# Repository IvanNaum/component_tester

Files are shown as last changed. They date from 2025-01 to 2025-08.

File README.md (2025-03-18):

# Component tester

## Naumov I

## Project Structure 

- [docs](docs/) - pdf documets/drafts
- [simulation](simulation/) - modeling of processes
- [software](software/) - common modules, tests, sdk and mcu software
- [hardware](hardware/) - schematics, PCB files
- [construction](construction/) - 3D models, CAD files

## Codestyles

1. Install pre-commit
```shell
pip install pre-commit
pre-commit install
```

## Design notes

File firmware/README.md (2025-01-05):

# Firmware 

## Project Structure 

- [common](common/) - contains common modules, host and tests
- [stm32f1_example/](stm32f1_example/) - led blink example on bluepill stm32f1
- [template/](template/) - template to copy to your project
- [host/](host/) - host platform project, allows to test common code on host

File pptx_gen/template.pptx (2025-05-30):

МИНИСТЕРСТВО НАУКИ И ВЫСШЕГО ОБРАЗОВАНИЯ РОССИЙСКОЙ ФЕДЕРАЦИИ
МОСКОВСКИЙ ГОСУДАРСТВЕННЫЙ ТЕХНИЧЕСКИЙ УНИВЕРСИТЕТ ИМ. Н.Э. БАУМАНА
КАФЕДРА ПРОЕКТИРОВАНИЕ И ТЕХНОЛОГИЯ ПРОИЗВОДСТВА ЭЛЕКТРОННОЙ АППАРАТУРЫ






Отчет о выполнении курсовой работы по предмету: «Электроника и микроэлектроника» на тему: «Тестер компонентов на базе микроконтроллера STM32F103C8T6»






Выполнил: студент группы ИУ4-62Б
Наумов И.К.
Проверил: Руководитель курсовой работы
Чистяков М.Г.



Москва, 2024 г.

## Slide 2

- {{E1.pdf}}

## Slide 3

- {{E2.pdf}}

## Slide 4

- {{E3.pdf}}

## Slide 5

- {{PE3.pdf}}

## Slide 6

- {{PP.pdf}}

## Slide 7

- {{SB.pdf}}

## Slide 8

- {{speka.pdf}}

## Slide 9

- {{modeling.pdf}}

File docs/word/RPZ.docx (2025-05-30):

Министерство науки и высшего образования Российской Федерации

Федеральное государственное бюджетное образовательное учреждение

высшего образования

«Московский государственный технический университет имени Н.Э. Баумана

(национальный исследовательский университет)»

(МГТУ им. Н.Э. Баумана)

ФАКУЛЬТЕТ «Информатика и системы управления» («ИУ»)

КАФЕДРА «Проектирование и технология производства электронной аппаратуры» («ИУ-4»)

РАСЧЕТНО-ПОЯСНИТЕЛЬНАЯ ЗАПИСКА

к курсовой работе на тему:

«Разработка устройства «Тестер компонентов на базе микроконтроллера STM32F103C8T6»

Студент | __________________________ | Наумов И. К.
| (Подпись, дата)
Руководитель курсовой работы | __________________________ | Чистяков М. Г.
| (Подпись, дата)

Москва, 2024
Аннотация

Работа описывает процесс разработки устройства «Тестера компонентов на базе микроконтроллера STM32F103C8T6». Данный тестер позволяет определять пассивные и активные компоненты

Работа содержит комплекс документов по разработке устройства: схема электрическая структурная; схема электрическая принципиальная; чертеж печатной платы; сборочный чертеж электронной ячейки; спецификация; перечень элементов. В заключении представлены выводы о проделанной работе и соответствии разработанного устройства техническому заданию.

Ключевые слова: тестер компонентов, контроль качества (AOI), STM32F103C8T6.

## Abstract

The work describes the development process of the "Component Tester Based on the STM32F103C8T6 Microcontroller." This tester allows identifying passive and active electronic components.

The work includes a comprehensive set of documentation for the device: a block diagram, an electrical schematic diagram, a printed circuit board (PCB) layout, an assembly drawing of the electronic unit, a specification, and a bill of materials. The conclusion summarizes the outcomes of the work and confirms that the developed device meets the technical requirements.

Keywords: component tester, quality control (AOI), STM32F103C8T6.

# СОДЕРЖАНИЕ

# Список условных обозначений, сокращений и терминов

ГОСТ – Государственный стандарт;

ДПП – Двухсторонняя печатная плата;

ЕСКД – Единая система конструкторской документации;

ПП – Печатная плата;

РПЗ – Расчётно-пояснительная записка;

РТЗ – Расширенное техническое задание;

ТЗ – Техническое задание;

ЭРЭ – Электрорадиоэлементы;

КМО – Компонент, монтируемый в отверстия

УГО – Условное графическое обозначение

# Введение

Работа посвящена разработке и исследованию устройства «Тестер компонентов на базе микроконтроллера STM32F103C8T6».

Целью работы является разработка устройства «Тестер компонентов на базе микроконтроллера STM32F103C8T6», разработка комплекта конструкторской документации, а также экспериментальное исследование устройства для выявления его соответствию техническим требованиям и пригодности к эксплуатации.

Для достижения поставленной задачи был решен следующий комплекс работ:

1. Разработка схемы электрической структурной (Э1);

2. Разработка схемы электрической функциональной (Э2);

3. Разработка схемы электрической принципиальной (Э3);

4. Моделирование работы устройства;

5. Разработка конструкции устройства;

6. Сборка опытного образца устройства;

7. Экспериментальные исследования устройства.

Исходными данными для работы являются:

- задание на выполнение курсовой работы;
- календарный план выполнения курсовой работы.

Результатами работы являются:

1. Схема электрическая структурная (Э1);
2. Схема электрическая функциональная (Э2);
3. Схема электрическая принципиальная (Э3);
4. Полнофункциональная модель в САПР “PSPICE 16.3”;
5. Чертеж печатной платы (ПП);
6. Сборочный чертеж (СБ);
7. Разработанный опытный образец;
8. Плакат демонстрационный.

# 1 Схемотехническое проектирование изделия «Тестер компонентов на базе микроконтроллера STM32F103C8T6»

Схемотехнический этап курсового проекта включает:

1. Разработка схемы электрической структурной (Э1) устройства;
2. Разработка схемы электрической функциональная (Э2) устройства;
3. Разработка схемы электрической принципиальной (Э3) устройства;
4. Подбор элементной базы устройства;
5. Разработка перечня элементов ПЭ3 устройства;

## 1.1 Разработка электрической структурной схемы (Э1)

Разработка схемы электрической структурной (Э1) предполагает первоначальную оценку работы и выделение основных структурных частей. Электрическая структурная схема устройства была разработана согласно ГОСТ 2.701-2008[7]. В качестве среды разработки была выбрана “Altium Designer 23.10.1”. Электрическая структурная схема изделия представлена на рисунке 1.1.

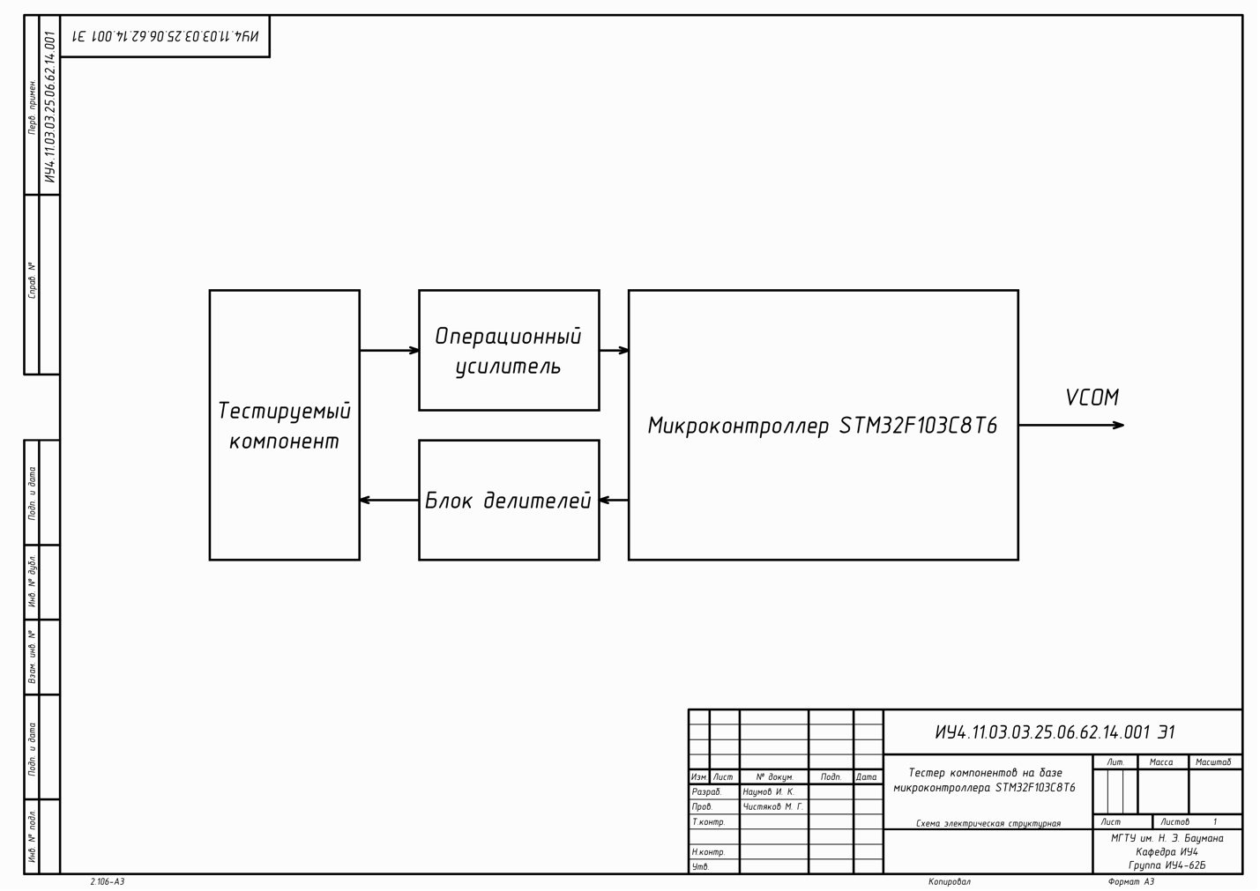
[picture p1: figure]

Рис. 1.1 – Электрическая структурная схема (Э1) устройства

Все устройство можно условно разделить на 3 функциональных блоков:

- Операционный усилитель – блок для снижение выходного сопротивления перед АЦП микроконтроллера.
- Блок делителей – набор резисторов, управляемые микроконтроллером для реализации деления напряжения в цепи тестирования компонента.
- Микроконтроллер – основной управляющий элемент устройства, обеспечивает корректность его работы.

## 1.2 Разработка электрической функциональной схемы (Э2)

На основе схемы электрической структурной схемы, была разработана схема электрическая функциональная. Схема разработана по ГОСТ 2.702-2011[8], и представлена на рисунке 1.2.

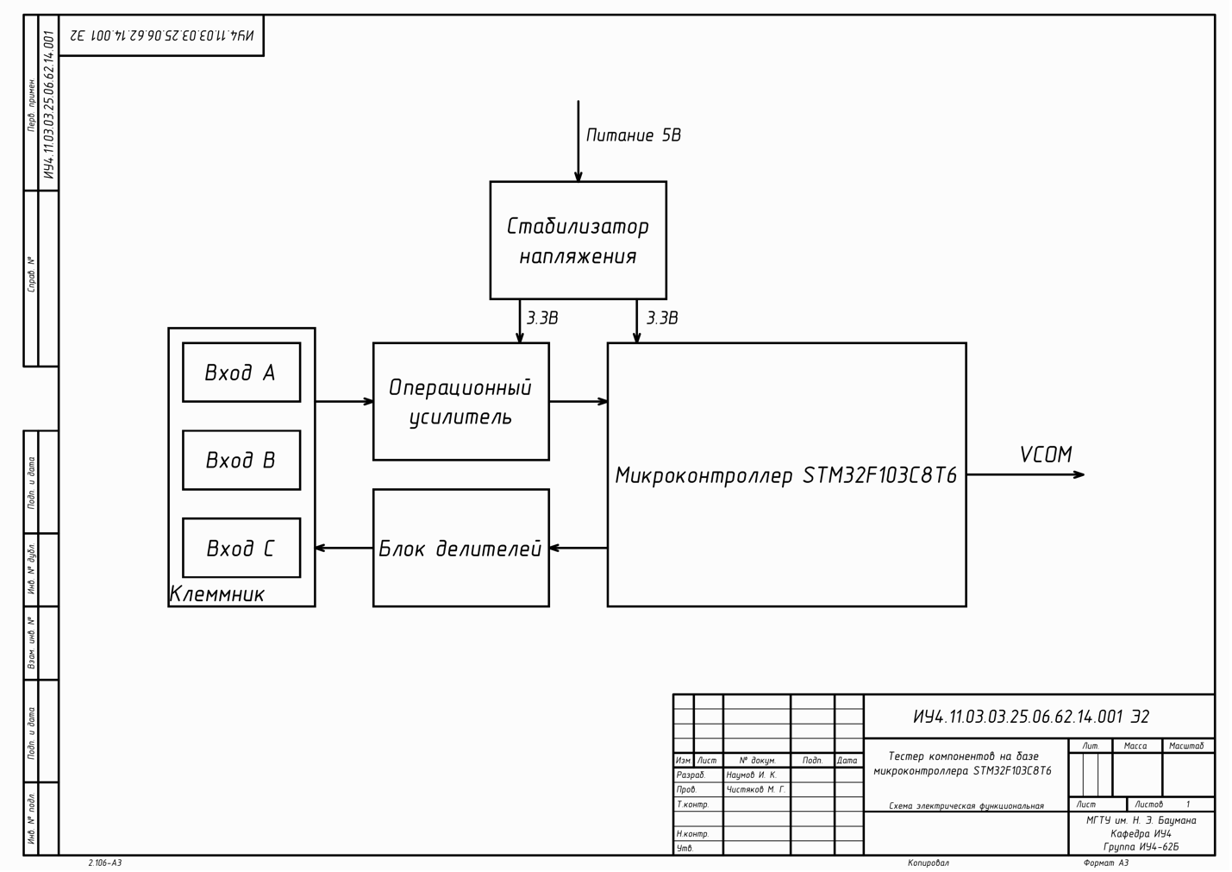
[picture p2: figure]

Рис. 1.2 – Электрическая функциональная схема (Э2) устройства

## 1.3 Разработка электрической принципиальной схемы (Э3)

На основе схемы электрической структурной схемы, была разработана схема электрическая принципиальная. Схема разработана по ГОСТ 2.702-2011[8], и представлена на рисунке 1.3.

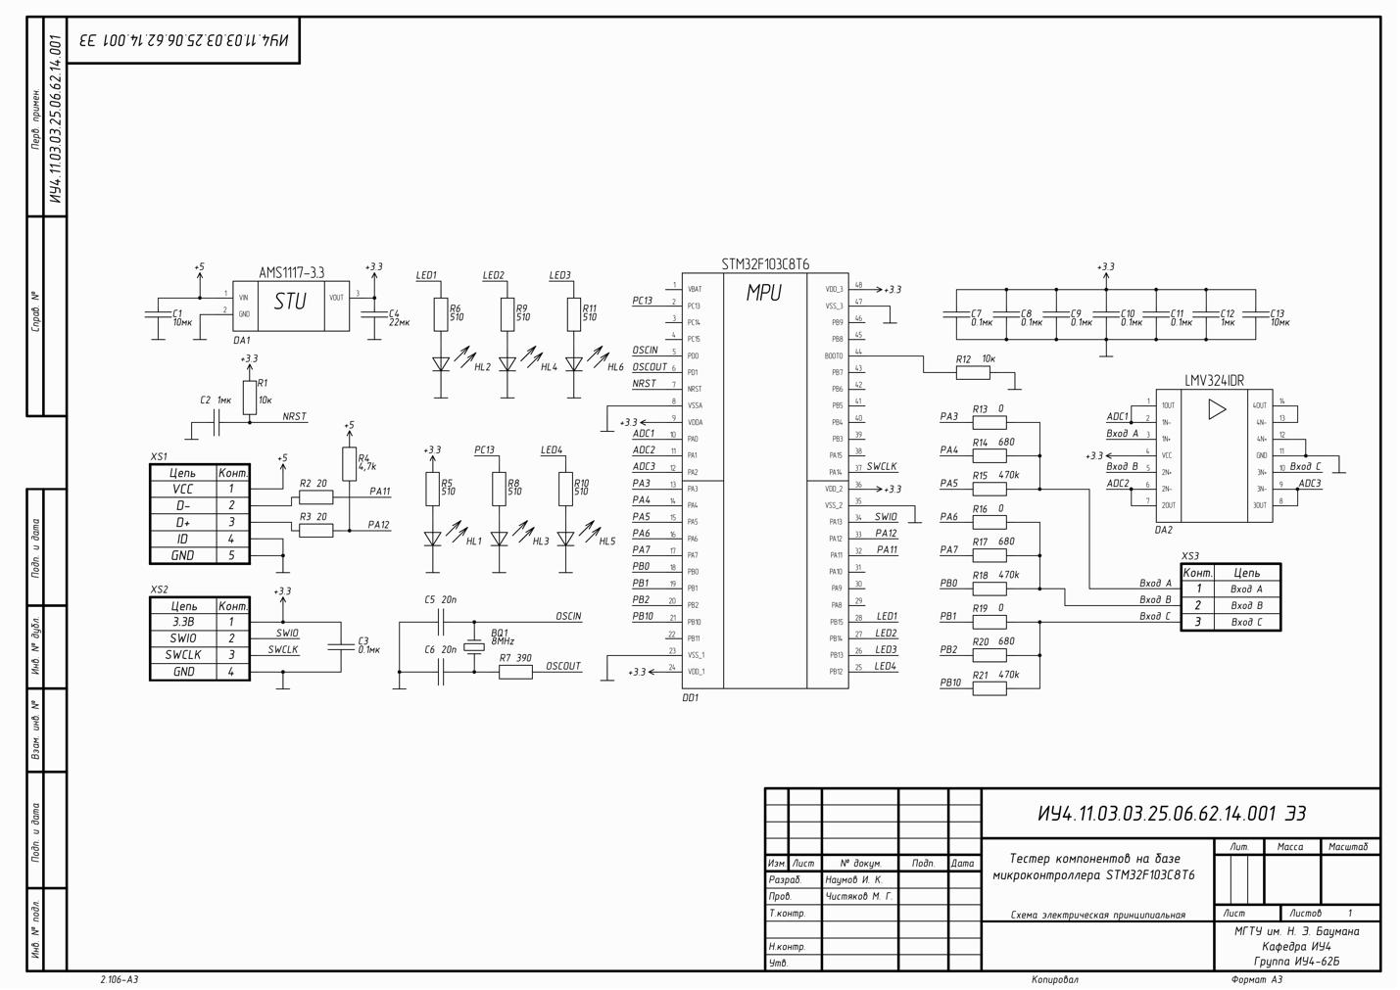
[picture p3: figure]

Рис. 1.3 – Электрическая принципиальная схема (Э3) устройства

Для индикации питания используется зелёный светодиод HL1, для пользовательской – красный HL3, для индикации тестируемого компонента – синие HL2, HL4, HL5, HL6. Формфактор 1206.

Разъём для программирования и отладки Serial Wire Debug (SWD) XS2 – PBS4, XS1 – USB type B mini, разъём для крепления тестируемого компонента XS3 – ZIF14.

Резисторы используются в формфакторе 1206, конденсаторы 0603.

Кварцевый резонатор BQ1 SMD 5×3.2 мм 8000 МГц.

Стабилизатор напряжения DA1 – AMS1117-3.3 3.3В 1А. Формфактор SOT-223.

Операционный усилитель DA2 – LMV324IDR, Низковольтный операционный усилитель, 1МГц, Rail-to-Rail. Формфактор SOIC-14.

Микроконтроллер DD1 – SMT32F103C8T6, Cortex-M3, 72МГц, 64КБ Flash. Формфактор LQFP-48.

## 1.4 Разработка перечня элементов (ПЭ3)

После выбора элементной базы был составлен перечень элементов схемы (ПЭ3) согласно ГОСТ 2.701-2008[7]. Перечень элементов (ПЭ3) представлен в документе ИУ4.11.03.03.25.06.62.15.001 ПЭ3 в приложении 1 и на рисунке 1.4.

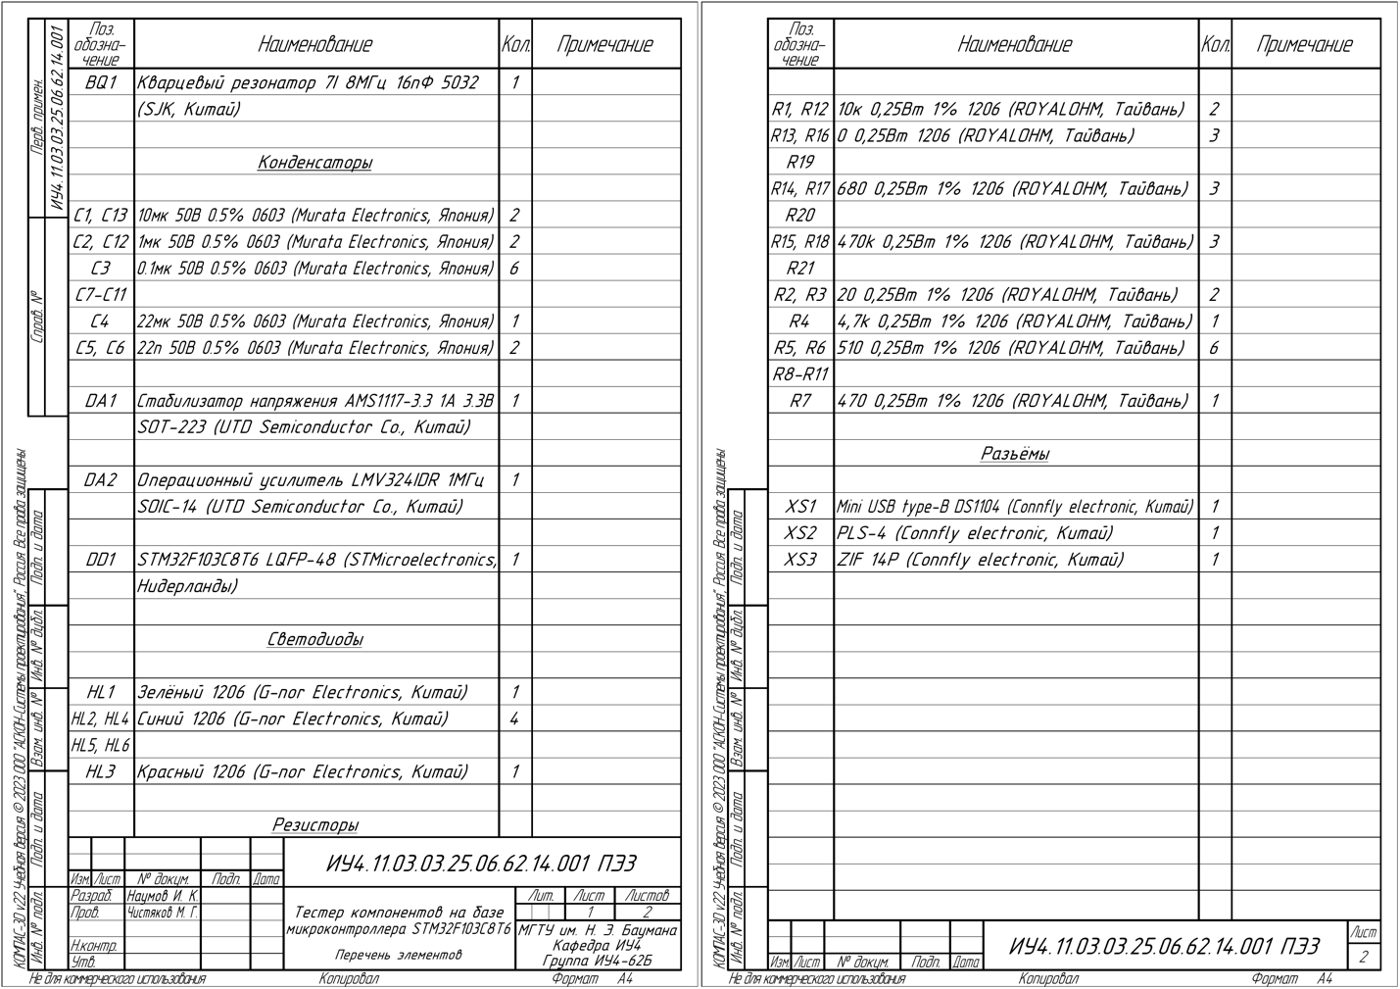
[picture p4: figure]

Рис. 1.4 – Перечень элементов (ПЭ3) устройства

## Вывод

В главе проведено схемотехническое проектирование изделия устройства «Тестер компонентов на базе микроконтроллера STM32F103C8T6». Была разработана схема электрическая структурная (Э1), в которой были выделены основные структурные узлы устройства. Данная схема представлена на чертеже ИУ4.11.03.03.25.06.62.15.001 Э1, а также на рисунке 1.1.

Далее была разработана схема электрическая функциональная (Э2), в которой функциональные соединения устройства. Данная схема представлена на чертеже ИУ4.11.03.03.25.06.62.15.001 Э2, а также на рисунке 1.2.

После была разработана схема электрическая принципиальная (Э3), в которой подробно описаны соединения всех ИЭТ устройства и благодаря условным графическим обозначениям однозначно определяется функционал каждого ИЭТ, а также обоснован выбор каждого ИЭТ. Данная схема представлена на чертеже ИУ4.11.03.03.25.06.62.15.001 Э3, а также на рисунке 1.3.

А также составлен перечень элементов. Документ ИУ4.11.03.03.25.06.62.15.001 ПЭ3 представлен в приложении 1 и на рисунке 1.4.

# 2 Описание алгоритма тестирования и моделирование устройства «Тестер компонентов на базе микроконтроллера STM32F103C8T6»

### Тестирование биполярных транзисторов

Исследование элемента необходимо начинать с обесточенным управляющим выводом (вывод С) исследуемого элемента. Во время испытания является базовым или отправным. Один испытательный вывод выбран положительной стороной элемента и подключен непосредственно к VCC. Другой испытательный вывод выбран отрицательной стороной элемента. Отрицательная сторона подсоединена через резистор 680 Ω к GND. Сначала, вывод C на 5 ms подключается через резистор 680 Ω Ом к GND и измеряется напряжение на отрицательной стороне. Далее вывод C переключается на Ввод (высокое полное входное сопротивление) и снова измеряется напряжение отрицательного испытательного вывода. Затем предполагаемая база соединяется через резистор 680 Ω на 5 ms к VCC и снова измеряется напряжение на отрицательной стороне. Если измеренное напряжение ниже первого результата измерения, то эта схема будет предполагаться, как правильная. Затем напряжение снова измеряется с обесточенным выводом C.

У биполярных транзисторов, имеющих повышенный обратный ток коллектора, он значительно повышается в режиме с обесточенной базой.

Если у элемента нет тока между положительным и отрицательным испытательными выводами без сигнала на выводе C, то переходим к тестам определения, описанным ниже. Если ток был обнаружен, то следующий тест описан в разделе о диодах.

Сначала измеряем коэффициент усиления предполагаемого P-N-P транзистора в схеме с общим коллектором (эмиттерный повторитель). Если напряжение базы (UB), измеренное с резистором 680 Ω, выше 9 mV, то коэффициент усиления вычисляется по формуле hFE = UE−UB. Напряжение UE это разность между напряжением на UB эмиттере и VCC. Если напряжение UB ниже 10 mV, измерение делают с резистором 470 kΩ в базе. В этом случае коэффициент усиления вычисляется по формуле hFE = UE·470000 / UB·680.

Затем делают тесты для предполагаемого P-N-P транзистора в схеме с общим эмиттером. Положительная сторона элемента теперь подключена прямо с VCC, отрицательная сторона через резистор 680 Ω подключена к GND. Если на отрицательной стороне элемента есть напряжение выше 1.6 V , когда базовый резистор 680 Ω подключен к GND, значит этот элемент P-N-P транзистор. Для того, чтобы измерить коэффициент усиления, в цепь базы вместо резистора 680 Ω включается резистор 470 kΩ. Коэффициент усиления вычисляется по формуле hFE =(UC −UC0)·470000 / UB·680. Напряжение UC0 является напряжением на коллекторном резисторе без базового тока. Как предполагается, правильным является более высокий коэффициент усиления, определенный первым или вторым способом.

Измерение N-P-N транзистора начинается таким же образом, как и P-N-P транзистора, с измерения коэффициента усиления в схеме с общим коллектором. Первое измерение сделано с резистором в цепи базы 680 Ω подключенным к VCC. Если напряжение на резисторе в цепи базы слишком низко, вместо 680 Ω берётся резистор 470 kΩ. Тогда измерение продолжается в схеме с общим эмиттером. Если напряжение коллектора ниже 1,6 V и резистор в цепи базы 680 Ω соединён с VCC, то это может быть N-P-N транзистор. Базовое напряжение N-P-N транзистора будет близко к напряжению эмиттера, таким образом, этот тип может быть идентифицирован определенно. Коэффициент усиления в схеме с общим эмиттером вычисляется по формуле hFE = (V CC−UC−UC0)·470000 / (V CC−UB)·(680+22).

### Тестирование диодов

Если предварительными тестами будет обнаружен ток, то элемент будет опознан как диод. Падение напряжения с резистором 680 Ω должно быть между 0,15 V и 3 V (в зависимости от расположения резистора).

### Тестирование резисторов

Измерение неизвестного резистора Rx осуществляется с использованием прецизионных резисторов 680 Ω. Схема этого измерения для испытательных выводов 1 и 2 представляет собой последовательное соединение прецизионного и тестируемого резистора. Величина резистора Rx может быть вычислена по известной величине резистора и измеренному напряжению, если отношение резистора Rx к 680 Ω не слишком велико. Теоретическое отклонение напряжения показано на рисунке 2.1 (слева), где величина резистора показана в логарифмическом масштабе.

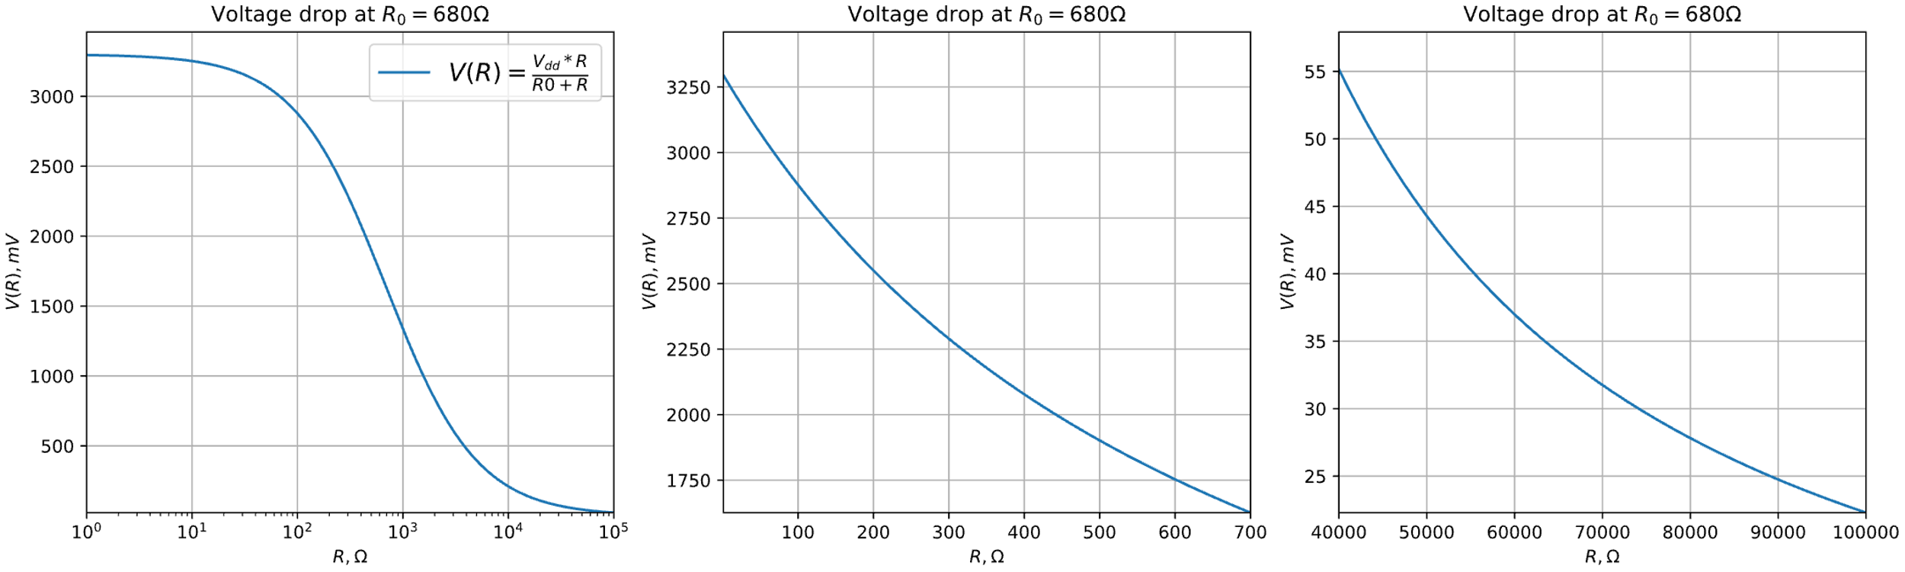
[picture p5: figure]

Рис. 2.1 – Падение напряжения при измерениях с резистором 680 Ω

График измерения на рисунке 2.1 (по центру) показан с измененным масштабом изображения для малых значений резисторов, на рисунке 2.1 (cправа) показан с измененным масштабом изображения для больших значений резисторов.

Для более высоких значений измеряемого резистора измерения проводятся с прецизионными резисторами 470 kΩ. Если все тесты свидетельствуют о том, что это не другой тип элемента, то полученная величина прямого и обратного измерений берется в качестве величины сопротивления резистора.

Теоретическое отклонение напряжения показано на рисунке 2.2 где величина резистора показана в логарифмическом масштабе. Теоретическое отклонение в этой диаграмме заканчивается на 100 MΩ, но фактическое значение для Тестера ограничено 60 MΩ, иначе устройство определяет, что резистор не подключен.

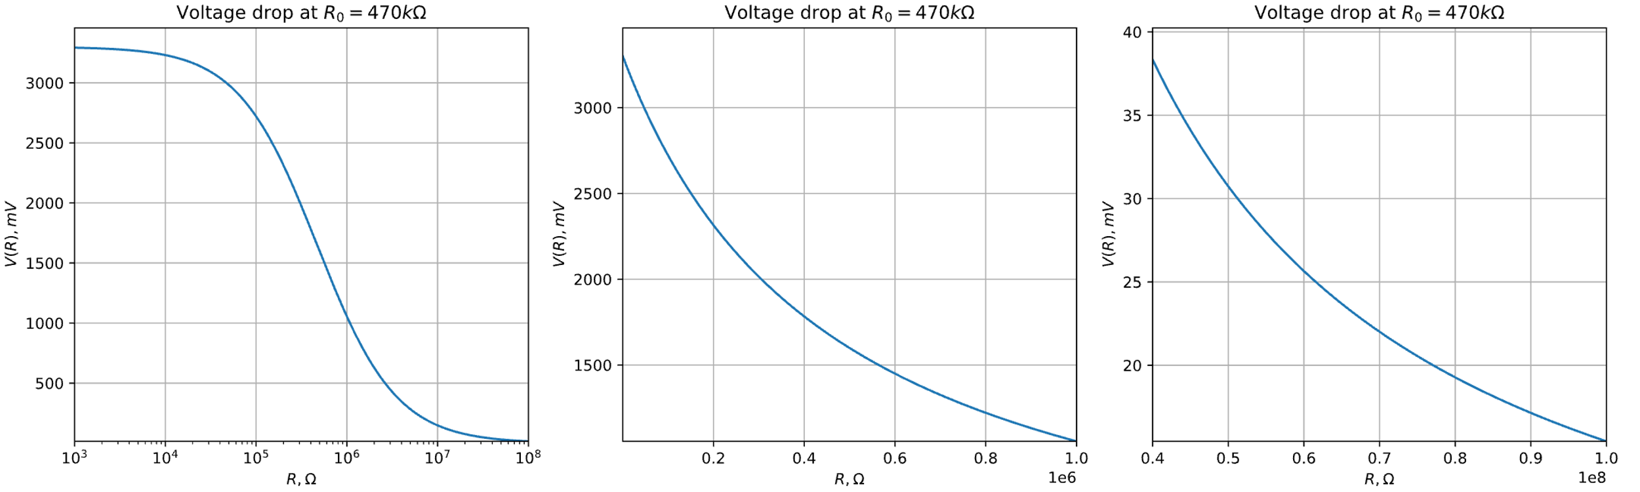
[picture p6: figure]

Рис. 2.2 – Падение напряжения при измерениях с резистором 470 kΩ

### Тестирование конденсаторов

Измерение величины ёмкости конденсаторов сделано, как отдельная задача измерения времени зарядки после всех других измерений. Положительный вывод конденсатора всегда подключен к испытательному выводу с более высоким номером (A). Если конденсатор измеряется параллельно с диодом, полярность может быть в другом порядке.

Необходимо разряжать конденсатор прежде, чем подсоединить его к устройству. Тестер дополнительно разряжает конденсатор перед любым измерением. Если напряжение ниже 1300 mV, конденсатор будет закорочен выходами порта, соединенными со входами порта АЦП.

Одна сторона конденсатора подключена к GND. Другая сторона конденсатора подключена через резистор 680 Ω к VCC на 10 ms. Впоследствии этот испытательный вывод будет переключён на ввод (высокий импеданс). После этого, 10 ms импульса тока, замеряется напряжение на конденсаторе без тока. Если напряжение не достигло минимального значения 300 mV, импульс зарядки будет повторен до 499 раз. Если после 127 импульсов не достигнуто минимальное напряжение 75 mV (приблизительно 0.2 s), дальнейшая зарядка будет остановлена, потому что 300 mV не смогут быть достигнуты остающимися импульсами зарядки. Пример тестирования конденсатора с величиной 10 mF показан на рисунке 2.3. Величина ёмкости вычисляется по количеству импульсов зарядки и величине достигнутого напряжения заряда из таблицы. Таблица содержит коэффициенты, чтобы получить значение в nF от времени зарядки и достигнутого напряжения с шагом 25 mV.

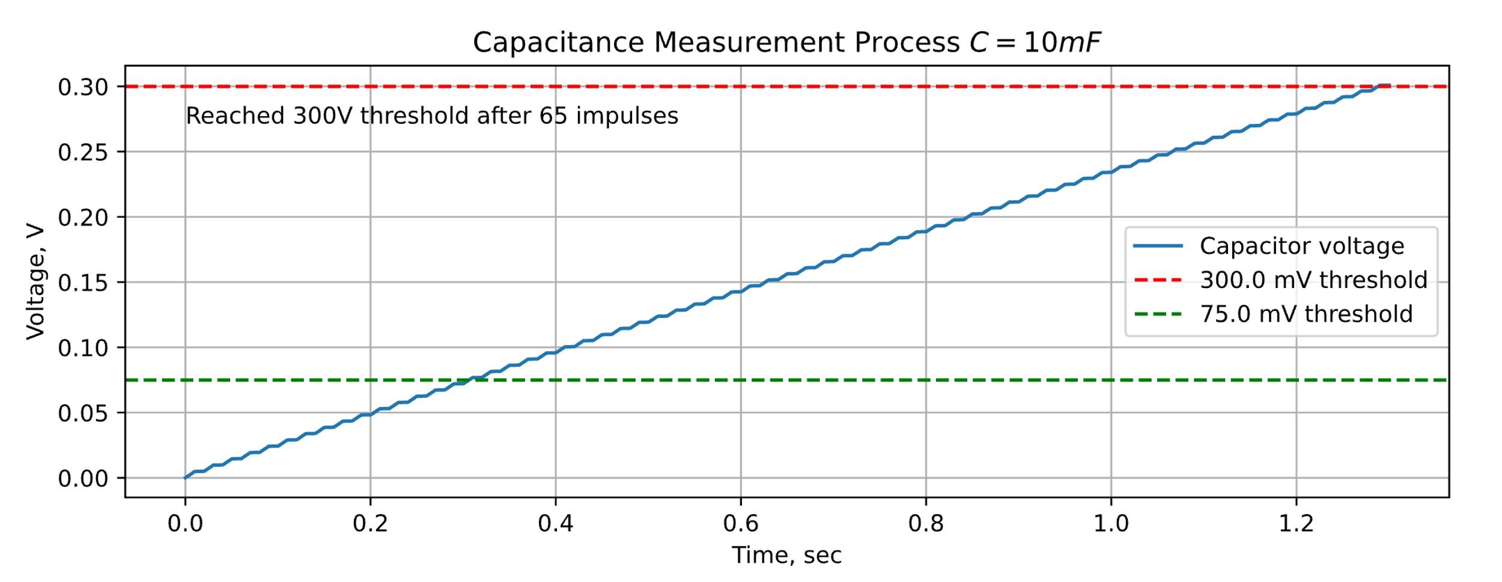
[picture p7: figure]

Рис. 2.3 –Напряжение на обкладках тестируемого конденсатора

После измерения ёмкости конденсатора будет проверен саморазряд ожиданием пропорционально периоду, который потребовала зарядка, и снова будет осуществлено считывание напряжения заряда. После чего полная ёмкость будет скорректирована. Возможный диапазон тестируемых конденсаторов с помощью данного метода показан на рисунке 2.4.

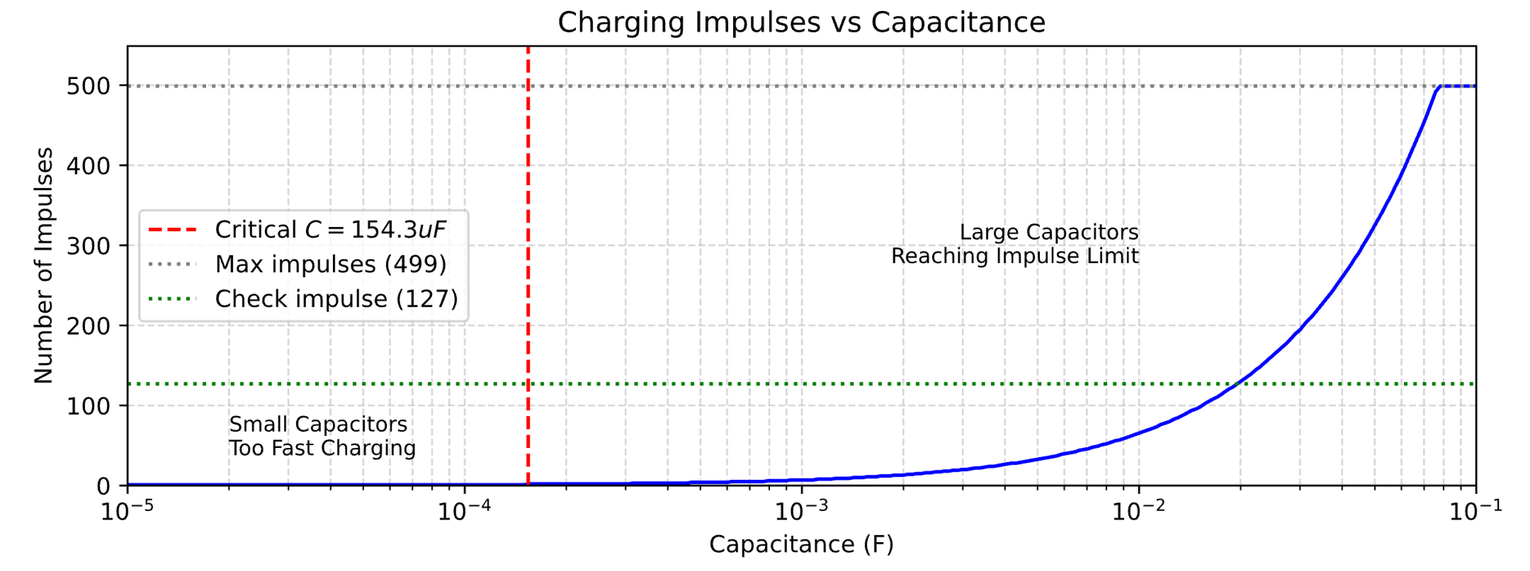
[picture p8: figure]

Рис. 2.4 – Диапазон тестируемых конденсаторов при заданном количестве импульсов

# 3 Конструкторско-технологическое проектирование устройства «Тестер компонентов на базе микроконтроллера STM32F103C8T6»

Конструкторско-технологический этап выполнения курсового проекта включает:

1. разработку топологии печатной платы (ПП);

2. разработку чертежа ПП;

3. разработку сборочного чертежа (СБ);

4. разработку спецификации (СП);

5. изготовление ПП и монтаж ЭРЭ.

## 3.1 Разработка топологии печатной платы (ПП)

В качестве среды разработки была выбрана программа для трассировки печатных плат «Altium Designer 23.10.1», результат работы представлен на рисунках 3.1 и 3.2:

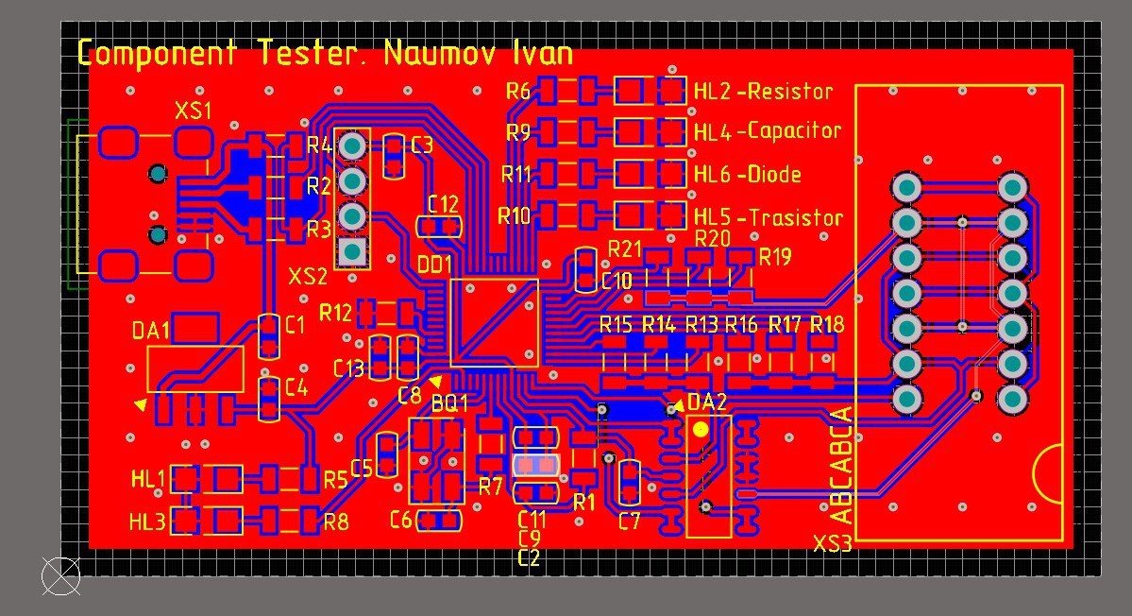
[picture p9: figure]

Рис. 3.1 – Трассировка ПП в программе “Altium Designer 23.10.1”

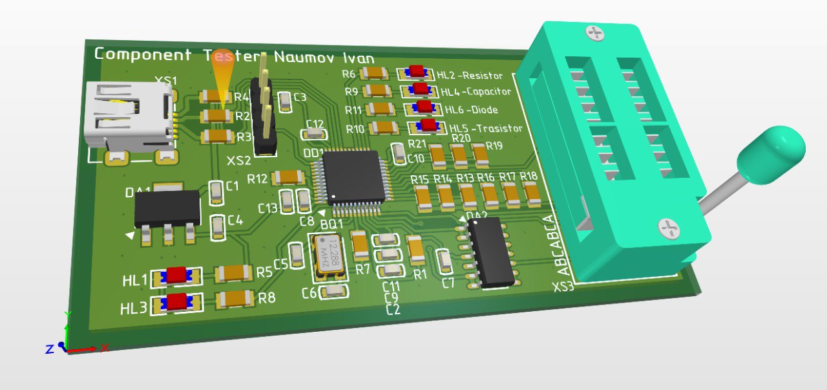
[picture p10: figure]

Рис. 3.2 – 3D-модель ячейки в программе “Altium Designer 23.10.1”

## 3.2 Разработка чертежа ПП

После трассировки был разработан чертеж ПП, который представлен на рисунке 3.3.

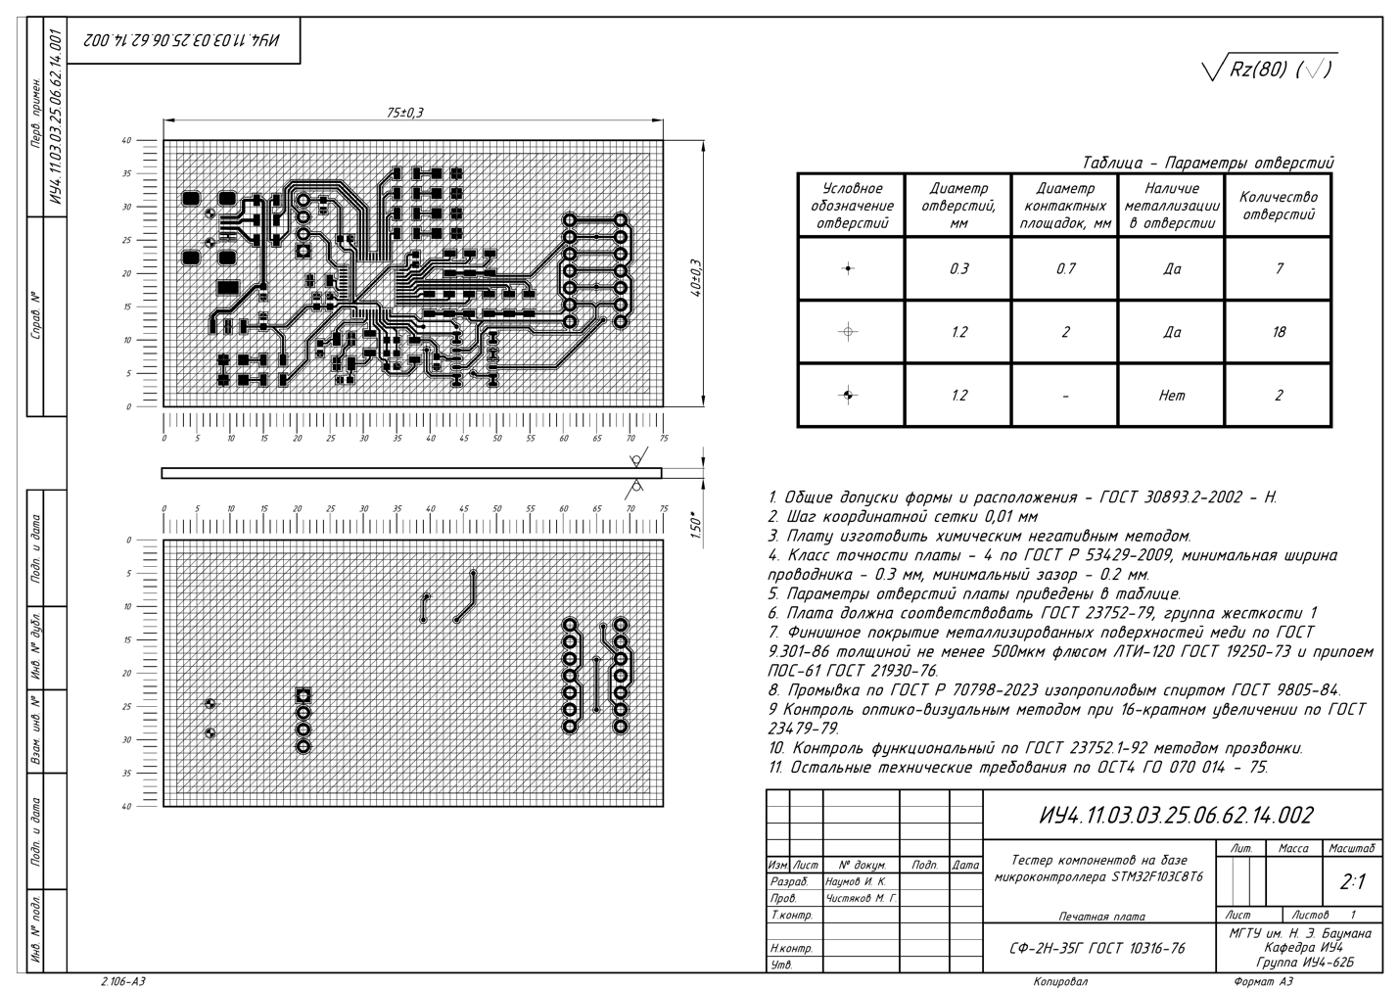
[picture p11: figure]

Рис. 3.3 – Чертеж печатной платы (ПП)

Плата представляет собой ДПП с габаритными размерами 75х40 мм. Проводящий рисунок изображен на рисунке 3.3 и на чертеже ИУ4.11.03.03.25.06.62.15.002.

Шаг координатной сетки 0.01 мм.

Плата соответствует требованиям ГОСТ 23752-79[9] (группа жёсткости 1).

Плата соответствует требованиям ГОСТ Р 53429-2009[10] (2 класс точности).

Минимальная ширина печатного проводника – 0.3 мм.

Минимальное расстояние между элементами проводящего рисунка – 0,2 мм.

Минимальный номинальный диаметр отверстия – 0,3 мм.

Материал платы – стеклотекстолит СФ-2Н-35Г ГОСТ 10316-76[11].

В печатной плате имеются отверстия различных типов, характеристика которых приведена в таблице 3.1, а также в таблице на чертеже ИУ4.11.03.03.25.06.62.15.002.

Таблица 3.1 – Таблица отверстий ПП

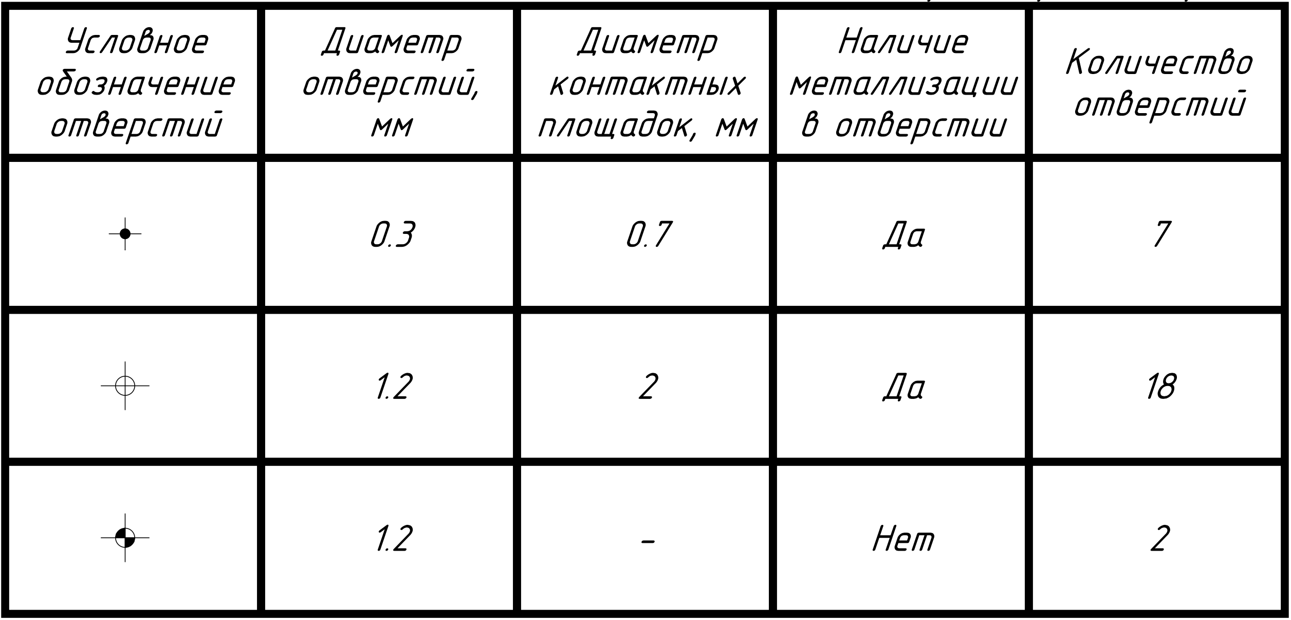
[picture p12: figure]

Общее количество отверстий – 27 отверстий.

Исходя из вышеперечисленных требований печатная плата опытного образца изготавливалась субтрактивным, негативным методом.

## 3.3 Разработка сборочного чертежа

Далее был разработан сборочный чертёж, представленный рисунке 3.4 и на чертеже ИУ4.11.03.03.25.06.62.15.001 СБ.

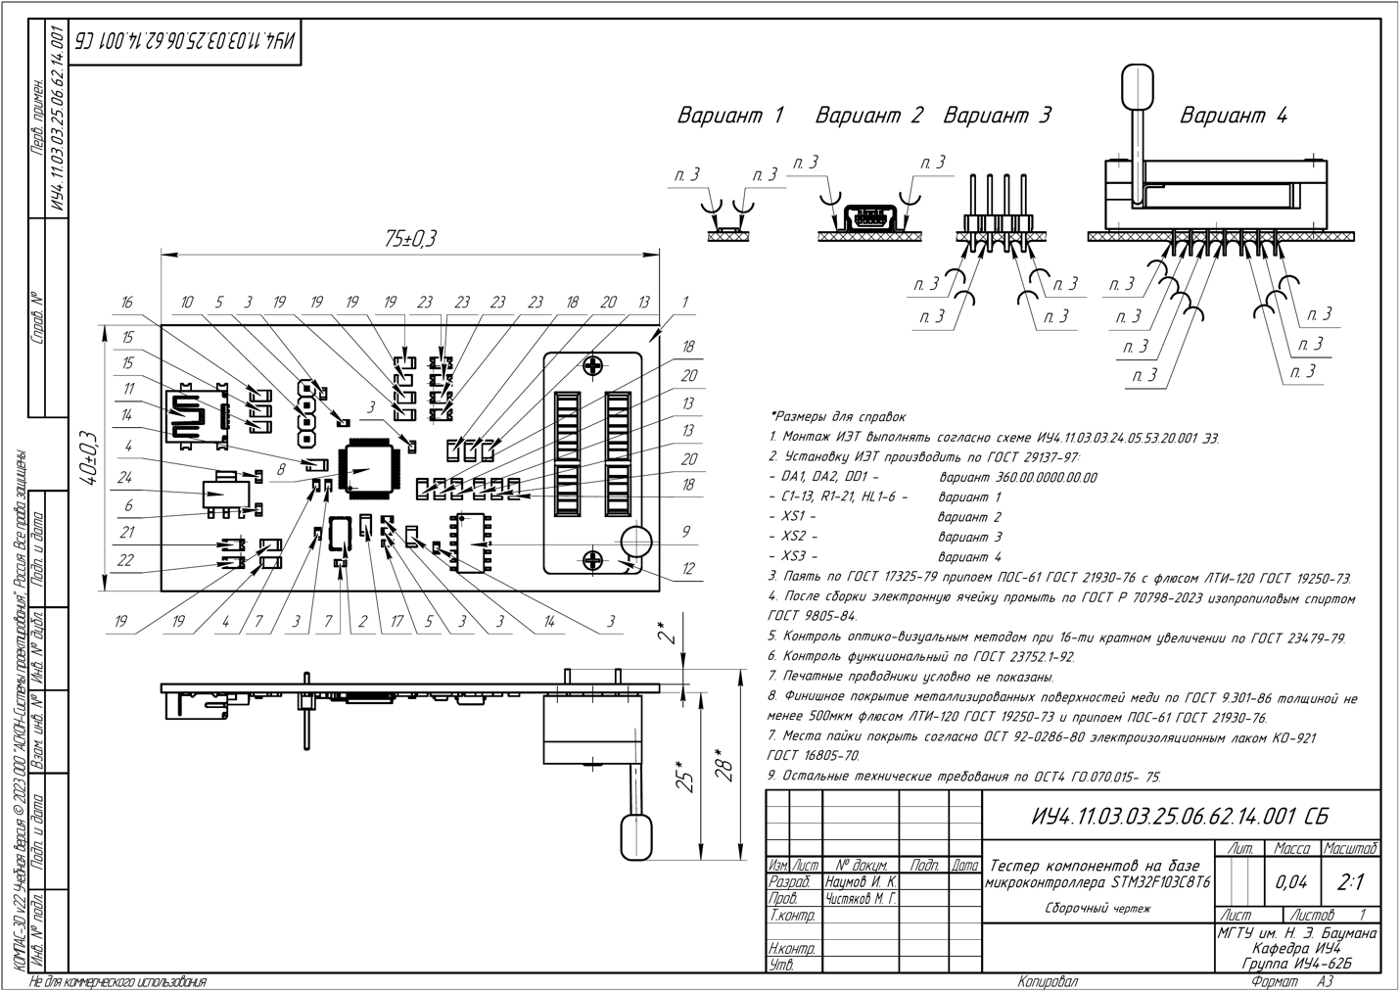
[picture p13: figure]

Рис. 3.4 – Сборочный чертеж электронной ячейки

Компоненты группируются по способу установки на плату. Установки формовка ИЭТ осуществляется согласно ГОСТ 29137-91[14]. Вариант установки приведены на чертеже ИУ4.11.03.03.25.06.62.15.001 СБ. Обозначения позиций согласно спецификации ИУ4.11.03.03.25.06.62.15.001.

Монтаж ИЭТ производится с одной стороны. Пайка выводов производится припоем ПОС-61 ГОСТ 21930-76[12] согласно ГОСТ 23592- 96[15]. Допускается применение импортного припоя. Габаритные размеры всего изделия составляют 75x40x28 мм. После сборки изделие промывают изопропиловым спиртом ГОСТ 9805-84. Контроль паяных соединений производится визуально-оптическим методом по ГОСТ 23479-79. Исходя из вышеперечисленных требований, при производстве опытного образца рекомендуется производить монтаж КМП припоем и капиллярной пайкой паяльником.

## 3.4 Разработка спецификации изделия

Спецификация – основной документ курсовой работы. В спецификацию вносят составные части, входящие в специфицируемое изделие, а также конструкторские документы, относящиеся к этому изделию и к его неспецифицируемым составным частям.

Спецификация на устройство была разработана согласно ГОСТ 2.106[18] в графическом редакторе «Компас-3D v23», представлена на рисунке 3.5 и состоит из следующих разделов в соответствующей последовательности:

− документация;

− детали;

− прочие изделия.

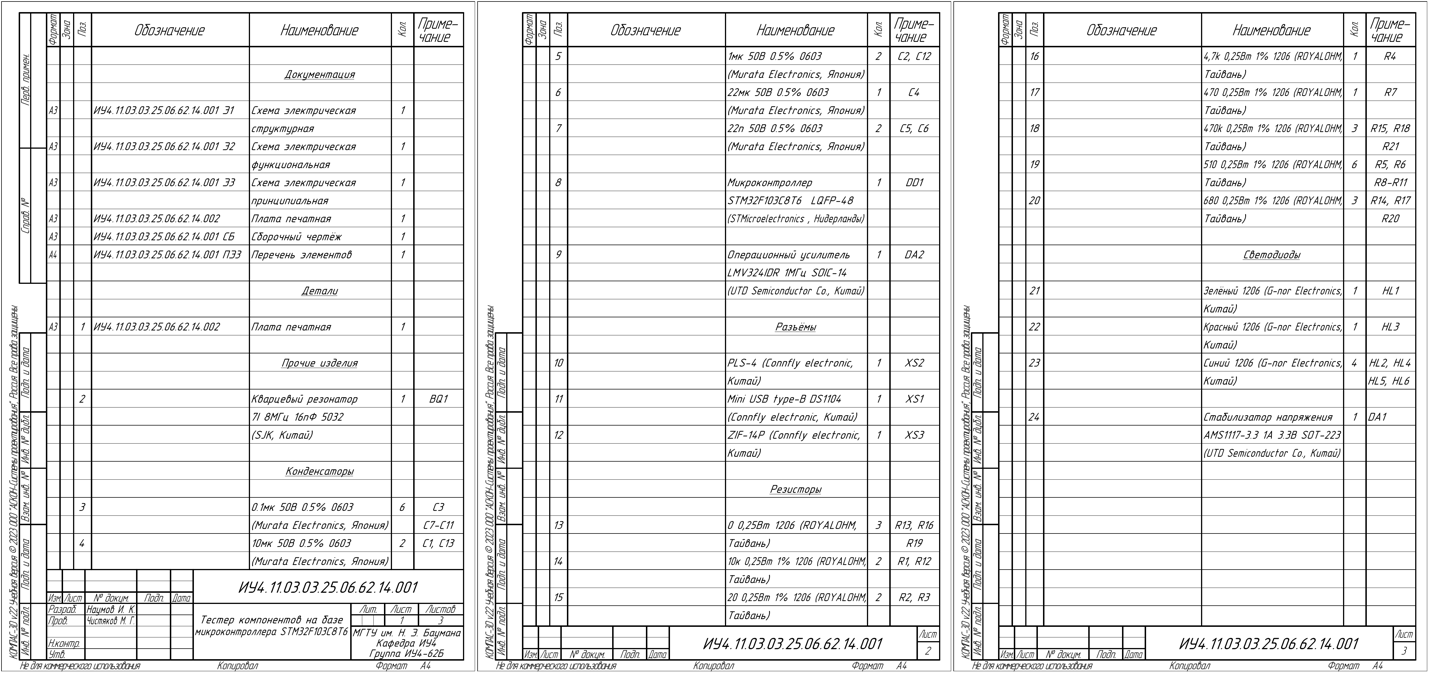
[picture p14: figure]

Рис. 3.5 – Спецификация на устройство

В раздел «Документация» внесены все документы, составляющие основной комплект конструкторских документов специфицируемого изделия, кроме самой спецификации и перечня элементов.

В раздел «Детали» была внесена деталь, непосредственно входящая в специфицируемое изделие – плата печатная.

Раздел «Прочие изделия» схож по наполнению с перечнем элементов (ПЭ3), за исключением того, запись изделий в пределах каждой группы происходит в алфавитном порядке наименований изделий, а обозначение УГО элементов записываются в графу «Примечание».

## 3.5 Изготовление ПП и монтаж ЭРЭ

Печатная плата изготавливалась на заводе компании «NextPCB» в соответствии с указанными выше требованиями.

Монтаж компонентов производился согласно схеме ИУ4.11.03.03.25.06.62.15.001 Э3. Фотография изготовленного устройства представлена на рисунке 2.6

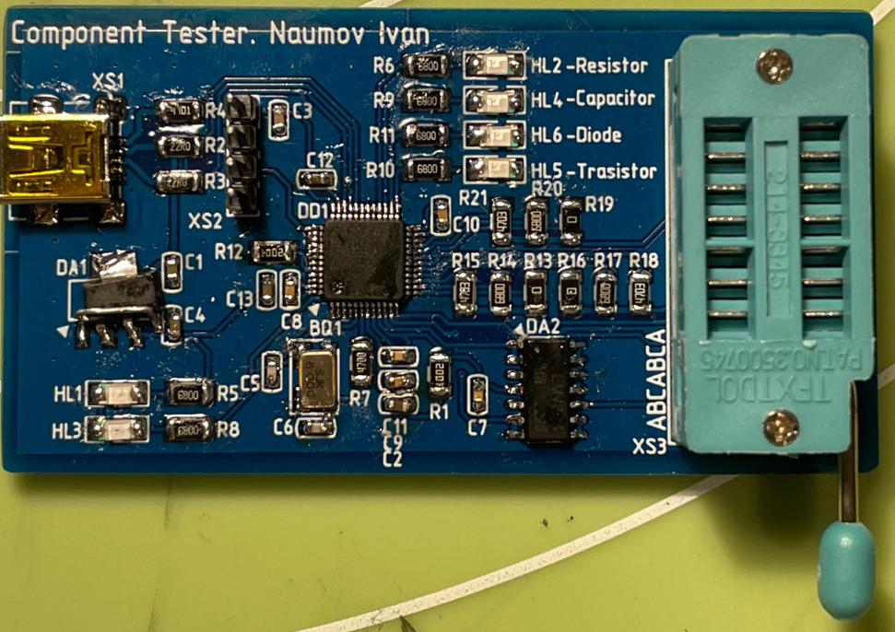
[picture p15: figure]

Рис. 3.6 – Реальный вид ячейки

## Выводы

В данной главе был описан процесс проектирования топологии печатной платы в САПР “Altium Designer 23.10.1” вместе с составлением 3D модели.

Разработанная топология ПП представлена на чертеже ИУ4.11.03.03.25.06.62.15.001. На основе него разработан сборочный чертеж – ИУ4.11.03.03.25.06.62.15.001 СБ. Была составлена спецификация устройства “Тестер компонентов на базе микроконтроллера STM32F103C8T6” – ИУ4.11.03.03.25.06.62.15.001. Изготовлена плата, установлены компоненты.

# 4 Экспериментальные исследования «Тестер компонентов на базе микроконтроллера STM32F103C8T6»

Экспериментальный этап выполнения курсового проекта состоит из:

1. Разработка методики проведения измерений характеристик устройства “Тестер компонентов на базе микроконтроллера STM32F103C8T6”;

2. Экспериментальное исследование характеристик устройства “Тестер компонентов на базе микроконтроллера STM32F103C8T6”.

## 4.1 Разработка методики проведения измерений характеристик изделия

Для проведения измерений необходимо:

− Обеспечить подключение к ПК;

− Подключить к разъёму на плате тестируемые компоненты.

## 4.2 Результаты экспериментального исследования изделия

В результате проведения экспериментов устройство полностью соответствует заявленным требованиям

## Выводы

В заключительной главе курсовой работы была разработана методика проведения измерений характеристик изделия “Тестер компонентов на базе микроконтроллера STM32F103C8T6”. Согласно этой методике, были произведены необходимые эксперименты.

# Заключение

В результате курсовой работы был проведен общетехнический обзор устройства “Тестер компонентов на базе микроконтроллера STM32F103C8T6”. На схемотехническом этапе разработки изделия “Тестер компонентов на базе микроконтроллера STM32F103C8T6” была разработана схема электрическая структурная (Э1), в которой были выделены основные структурные узлы устройства. Далее схема электрическая функциональная (Э2). После, последовала разработка схемы электрической принципиальной (Э3), в которой подробно описаны соединения всех ИЭТ устройства. Помимо этого, был обоснован выбор элементов изделия и на основе этого составлен перечень элементов ПЭ3. На конструкторско-технологическом этапе разработки изделия “Тестер компонентов на базе микроконтроллера STM32F103C8T6” были выбран тип ПП, расположение печатных проводников, а также базовый материал ПП. В результате разработана топология ПП изделия. На основе разработанной 3D модели устройства был составлен СБ. Были выбраны варианты установки компонентов на плату, а в результате анализа электрических соединений был выбран припой для установки КМП и КМО на ПП.

На этапе экспериментального исследования устройства “Тестер компонентов на базе микроконтроллера STM32F103C8T6” был разработан экспериментальный стенд для изделия. Разработана методика проведения эксперимента для выяснения работоспособности устройства. Согласно данной методике произведены экспериментальные измерения и составлены результаты работы изделия. Сделано сравнение результатов моделирования и экспериментального исследования, сделаны выводы о правильности работы устройства и о соответствии разработанного устройства требованиям технического задания.

В итоге проделанной работы можно сделать вывод, что разработанное изделия “Тестер компонентов на базе микроконтроллера STM32F103C8T6” соответствует требованиям технического задания.

# Список используемых источников

1. Хейс Т. К., Искусство схемотехники. Теория и практика: Пер. с англ. / Т. К. Хейс, П. Хоровиц. — СПб.: БХВ-Петербург, 2022. — 1200 с.: ил.

2. Хоровиц, Х. Искусство схемотехники / Х. Хоровиц, У. Хилл. — 5- е изд. переработанное. — Москва : Мир, 1997. — 704 c.

3. Джонс, М. Х. Электроника - практический курс / М. Х. Джонс. — Москва : Постмаркет, 199. — 528 c.

4. Монк, С. Электроника: теория и практика / С. Монк, П. Шерц. — СПб. : БВХ-Петербург, 2018. — 1168 c.Пирогова, Е. В. Проектирование и технология печатных плат: учебник / Е. В. Пирогова. — М. : ФОРУМ: ИНФРА-М, 2005. — 560 c.

5. Проектирование коммутационных структур электронных средств: учеб. пособие / В.Н. Гриднев, Г. Н. Гриднева – М.: Изд-во МГТУ им. Н.Э.Баумана, 2014 – 344 с.: ил. (Библиотека “Конструирование и технология электронных средств” в 25 кн. Кн.7).

6. Конструкторско-технологическое проектирование электронной аппаратуры : учебник для вузов / Билибин К. И., Власов А. И., Журавлева Л. В. [и др.] ; ред. Шахнов В. А. - 2-е изд., перераб. и доп. - М. : Изд-во МГТУ им. Н. Э. Баумана, 2005. - 563 с.

7. ГОСТ 2.701-2008 Единая система конструкторской документации (ЕСКД). Схемы. Виды и типы. Общие требования к выполнению (с Поправкой).

8. ГОСТ 2.702-2011 Единая система конструкторской документациии (ЕСКД). Правила выполнения электрических схем.

9. ГОСТ 23752-79 Платы печатные. Общие технические условия (С изменениями No1-5).

10. ГОСТ Р 53429-2009 Платы печатные. Основные параметры конструкции.

11. ГОСТ 10316-78 Гетинакс и стеклотекстолит фольгированные. Технические условия (с Изменениями No1-6).

12. ГОСТ 21930-76 Припои оловянно-свинцовые в чушках. Технические условия (с Изменениями No1,2,3,4).

13. ГОСТ 11284-75 Отверстия сквозные под крепежные детали. Размеры (С изменением No1).

14. ГОСТ 29137-91 Формовка выводов и установка изделий электронной техники на печатные платы. Общие требования и нормы конструирования.

15. ГОСТ 23592-96 Монтаж электрический радиоэлектронной аппаратуры и приборов. Общие требования к объемному монтажу изделий электронной техники и электротехнических.

16. ГОСТ 18300-87 Спирт этиловый ректификованный технический. Технические условия.

17. ГОСТ 24715-81 Соединения паяные. Методы контроля качества.

18. ГОСТ 2.106 Единая система конструкторской документации (ЕСКД). Текстовые документы (с Изменением No1).

19. ГОСТ 30893.1-2002 Общие допуски. Предельные отклонения линейных и угловых размеров с неуказанными допусками.

20. ГОСТ 30893.2-2002 Общие допуски. Допуски формы и расположение поверхностей, не указанные индивидуально.

21. ГОСТ 26246.5-89 Материал электроизоляционный фольгированный нормированной горючести для печатных плат на основе стеклоткани, пропитанной эпоксидным связующим.

# Приложение 1

Децимальный номер | Наименование
- | Техническое задание
- | Календарный план
ИУ4.11.03.03.25.06.62.15.001 Э1 | Схема электрическая структурная
ИУ4.11.03.03.25.06.62.15.001 Э2 | Схема электрическая функциональная
ИУ4.11.03.03.25.06.62.15.001 Э3 | Схема электрическая принципиальная
ИУ4.11.03.03.25.06.62.15.001 ПЭ3 | Перечень элементов
ИУ4.11.03.03.25.06.62.15.002 | Чертёж печатной платы
ИУ4.11.03.03.25.06.62.15.001 СБ | Сборочный чертёж
ИУ4.11.03.03.25.06.62.15.001 | Спецификация
- | Плакат демонстрационный
- | https://github.com/IvanNaum/component_tester

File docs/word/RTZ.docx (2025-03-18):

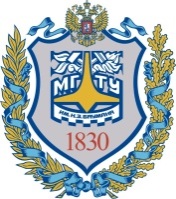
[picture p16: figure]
Gerb-BMSTU_01

| Министерство науки и высшего образования Российской Федерации Федеральное государственное бюджетное образовательное учреждение высшего образования «Московский государственный технический университет имени Н.Э. Баумана (национальный исследовательский университет)» (МГТУ им. Н.Э. Баумана)

ФАКУЛЬТЕТ «Информатика и системы управления» («ИУ»)

КАФЕДРА «Проектирование и технология производства электронной аппаратуры» («ИУ4»)

РАСШИРЕННОЕ ТЕХНИЧЕСКОЕ ЗАДАНИЕ

НА ВЫПОЛНЕНИЕ КУРСОВОЙ РАБОТЫ:

«Тестер компонентов на базе микроконтроллера STM32F103C8T6»

Дата выдачи задания «___» ____________ 20__ г.

Руководитель курсовой работы | | М. Г. Чистяков
| (Подпись, дата) | (И.О.Фамилия)
Студент | | Наумов И. К.
| (Подпись, дата) | (И.О.Фамилия)

РАСШИРЕННОЕ ТЕХНИЧЕСКОЕ ЗАДАНИЕ

Настоящее техническое задание распространяется на разработку устройства «Тестер компонентов на базе микроконтроллера STM32F103C8T6».

1 ОСНОВАНИЕ ДЛЯ ВЫПОЛНЕНИЯ РАБОТЫ

Основанием для выполнение курсовой работы по предмету «Схемотехника электронных средств» является задание кафедры ИУ4 «Проектирование и технология производства электронной аппаратуры» в соответствии с учебным планом специальности 11.03.03 «Конструирование и технология электронных средств» (бакалавр).

2 ЦЕЛИ И ЗАДАЧИ РАБОТЫ

Целью выполнения курсовой работы является разработка конструкторской документации, разработка и изготовление опытного образца устройства «Тестер компонентов на базе микроконтроллера STM32F103C8T6». Разрабатываемое устройство предназначено для проверки работоспособности радиоэлектронных компонентов.

В ходе выполнения курсовой работы должны быть решены следующие задачи:

1. Анализ существующих процедур тестирования компонентов.

2. Теоретическое исследование процедур тестирования компонентов.

3. Разработка устройства «Тестер компонентов на базе микроконтроллера STM32F103C8T6».

4. Проектирование устройства «Тестер компонентов на базе микроконтроллера STM32F103C8T6».

5. Отладка устройства «Тестер компонентов на базе микроконтроллера STM32F103C8T6».

6. Экспериментальное исследование устройства «Тестер компонентов на базе микроконтроллера STM32F103C8T6».

7. Разработка технического задания (ТЗ) на квалификационную работу бакалавра.

3 ТРЕБОВАНИЯ К ВЫПОЛНЕНИЮ КУРСОВОЙ РАБОТЫ

3.1 Основные требования:

3.1.1 В ходе выполнения курсовой работы должны быть проведены теоретические и экспериментальные исследования с целью решения задач, указанных в п. 2. настоящего ТЗ.

3.1.2 Разработанное в ходе работы устройство «Тестер компонентов на базе микроконтроллера STM32F103C8T6» должно соответствовать следующим требования:

- Входное напряжение: 5В (постоянное).
- Тестировать компоненты:
  - Резисторы
  - Конденсаторы
  - NPN и PNP биполярные транзисторы
- Рабочий температурный диапазон: 0…+35ºС

3.1.3 Устройство должно питаться 5В и обеспечивать передачу данных по USB с использованием виртуального COM-порта.

3.1.4 Информация о тестируемом компоненте должна содержать данные о типе компонента и последовательности подключенных выводов.

3.1.5 Печатная плата устройства не должна превышать габариты 75мм×75мм и соответствовать не более 4-му классу точности, а топологический рисунок должен быть выполнен не более чем в 2-х слоях.

3.1.6 Правильность работы разработанного устройства должна быть подтверждена результатами схемотехнического моделирования в одном из доступных программных пакетов на базе SPICE моделей.

3.2 Требования к способам и точности обработки результатов исследований.

Не предъявляются.

3.3 Требования к проведению моделирования.

Не предъявляются.

3.4 Требования к проведению патентных исследований и составлению отчета о них.

В ходе выполнения курсовой работы проведение проверки патентной чистоты разработанного подхода не требуется.

Государственная регистрация программы для ЭВМ в едином реестре программного обеспечения РосПатента не требуется.

3.5 Предполагаемые результаты курсовой работы

В результате выполнения курсовой работы должны быть получены следующие результаты:

- по п.2 подготовлен сравнительный анализ существующих решений и устройств «Тестер компонентов на базе микроконтроллера STM32F103C8T6». Выявлены наилучшие имеющиеся решения, а также существующие проблемы.
- по п.3.1 разработано устройство, соответствующее требованиям расширенного технического задания.

3.6 Необходимость разработки, изготовления и испытаний макетов.

В результате работы должен быть собран рабочий макет устройства на печатной плате по разработанному входе работы чертежу печатной платы. Электрические соединения между компонентами макета должны быть выполнены только с помощью печатных проводников. Макет должен также полностью отвечать требованиям технического задания, приведенным в п.3 настоящего ТЗ.

4 ТЕХНИЧЕСКИЕ ТРЕБОВАНИЯ К ОБРАЗЦУ

Созданный в ходе выполнения курсовой работы макетный образец устройства «Тестер компонентов на базе микроконтроллера STM32F103C8T6» должен соответствовать требования приведенным в п.3 настоящего ТЗ.

5 ЭТАПЫ КУРСОВОЙ РАБОТЫ

№ п/п | Наименование этапа. Содержание работ по этапу | Выдаваемая научно- техническая продукция | Сроки выполнения
1 | ТЕОРЕТИЧЕСКАЯ И ЭКСПЕРИМЕНТАЛЬНАЯ РАБОТА. Содержание этапа: 1. Техническое задание и календарный план 2. Расширенное техническое задание 3. Схема электрическая структурная (Э1) 4. Схема электрическая функциональная (Э2) 5. Результаты моделирование устройства 6. Схема электрическая принципиальная и перечень элементов 7. Чертеж печатной платы 8. Сборочный чертеж и спецификация 9. Сборка устройства и его экспериментальное исследование 10. РПЗ и демонстрационные плакаты | Согласно п.6 настоящего ТЗ | 01.05.2025

6 ТРЕБОВАНИЯ К РАЗРАБАТЫВАЕМОЙ ДОКУМЕНТАЦИИ

В ходе выполнения курсовой работы должен быть подготовлен следующий минимальный комплект конструкторской документации:

- Расширенное техническое задание.
- Схема электрическая структурная (Э1).
- Схема электрическая функциональная (Э2).
- Схема электрическая принципиальная (Э3).
- Чертеж печатной платы.
- Сборочный чертеж.
- Спецификация на устройство.
- Схема тестирования устройства.
- Экспериментальное исследование устройства.
- Перечень элементов на электрическую принципиальную схему (ПЭ3).
- Расчетно-пояснительная записка (РПЗ).

Разрабатываемый комплект документов должен быть подготовлен в соответствии с требованиями действующего регламента кафедры ИУ4, а также Государственных Стандартов Российской Федерации (в том числе ГОСТ 7.32-2017). Кроме этого, РПЗ должна содержать максимально подробное описание примененных схемотехнических и конструкторских решений, а также в ней должны быть представлены все расчеты, подтверждающие правильность выбранных студентом подходов и решений. РПЗ должна быть предоставлена в электронном виде (в формате Office Open XML) и на бумажном носителе (в одном экземпляре).

7 ТРЕБОВАНИЯ ПО ОБЕСПЕЧЕНИЮ СОХРАНЕНИЯ ГОСУДАРСТВЕННОЙ ТАЙНЫ ПРИ ВЫПОЛНЕНИИ КУРСОВОЙ РАБОТЫ

Не предъявляются.

8 ТЕХНИКО-ЭКОНОМИЧЕСКИЕ ТРЕБОВАНИЯ

Не предъявляются.

9 СРОКИ ВЫПОЛНЕНИЯ КУРСОВОЙ РАБОТЫ

Срок выполнения курсовой – 1 мая 2025 года.

10 Исполнитель курсовой работы

| | должность, исполнитель, курсовой работы
| | подпись, инициалы, фамилия
| | «___»__________________________20 _г.

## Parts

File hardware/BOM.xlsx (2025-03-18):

Comment | Footprint | Раздел | Бренд | Страна | Название | Корпус | Fullname | Quantity | Designator
8MHz | Crystal Resonator | Кварцевый резонатор | SJK | Китай | 7I 8МГц 16пФ | 5032 | 7I 8МГц 16пФ 5032 (SJK, Китай) | 1 | BQ1
10мк | C SMD 0603 | Конденсатор | Murata Electronics | Япония | 10мк 50В 0.5% | 0603 | 10мк 50В 0.5% 0603 (Murata Electronics, Япония) | 2 | C1, C13
1мк | C SMD 0603 | Конденсатор | Murata Electronics | Япония | 1мк 50В 0.5% | 0603 | 1мк 50В 0.5% 0603 (Murata Electronics, Япония) | 2 | C2, C12
0.1мк | C SMD 0603 | Конденсатор | Murata Electronics | Япония | 0.1мк 50В 0.5% | 0603 | 0.1мк 50В 0.5% 0603 (Murata Electronics, Япония) | 6 | C3, C7, C8, C9, C10, C11
22мк | C SMD 0603 | Конденсатор | Murata Electronics | Япония | 22мк 50В 0.5% | 0603 | 22мк 50В 0.5% 0603 (Murata Electronics, Япония) | 1 | C4
22п | C SMD 0603 | Конденсатор | Murata Electronics | Япония | 22п 50В 0.5% | 0603 | 22п 50В 0.5% 0603 (Murata Electronics, Япония) | 2 | C5, C6
Stabilizer | SOT230P695X180-4N | Стабилизатор напряжения | UTD Semiconductor Co. | Китай | AMS1117-3.3 1А 3.3В | SOT-223 | AMS1117-3.3 1А 3.3В SOT-223 (UTD Semiconductor Co., Китай) | 1 | DA1
OpAmp LM358DR [SOIC-14] | SOP127P600X175-14N | Операционный усилитель | UTD Semiconductor Co. | Китай | LMV324IDR 1МГц | SOIC-14 | LMV324IDR 1МГц SOIC-14 (UTD Semiconductor Co., Китай) | 1 | DA2
STM32F103C8T6 [LQFP-48] | STM32 [LQFP-48] | Микроконтроллер | STMicroelectronics | Нидерланды | STM32F103C8T6 | LQFP-48 | STM32F103C8T6 LQFP-48 (STMicroelectronics , Нидерланды) | 1 | DD1
LED | Led 1206 | Светодиод | G-nor Electronics | Китай | Зелёный | 1206 | Зелёный 1206 (G-nor Electronics, Китай) | 1 | HL1
LED | Led 1206 | Светодиод | G-nor Electronics | Китай | Синий | 1206 | Синий 1206 (G-nor Electronics, Китай) | 4 | HL2, HL4, HL5, HL6
LED | Led 1206 | Светодиод | G-nor Electronics | Китай | Красный | 1206 | Красный 1206 (G-nor Electronics, Китай) | 1 | HL3
10к | R_SMD_1206 | Резистор | ROYALOHM | Тайвань | 10к 0,25Вт 1% | 1206 | 10к 0,25Вт 1% 1206 (ROYALOHM, Тайвань) | 2 | R1, R12
0 | R_SMD_1206 | Резистор | ROYALOHM | Тайвань | 0 0,25Вт | 1206 | 0 0,25Вт 1206 (ROYALOHM, Тайвань) | 3 | R13, R16, R19
680 | R_SMD_1206 | Резистор | ROYALOHM | Тайвань | 680 0,25Вт 1% | 1206 | 680 0,25Вт 1% 1206 (ROYALOHM, Тайвань) | 3 | R14, R17, R20
470k | R_SMD_1206 | Резистор | ROYALOHM | Тайвань | 470k 0,25Вт 1% | 1206 | 470k 0,25Вт 1% 1206 (ROYALOHM, Тайвань) | 3 | R15, R18, R21
20 | R_SMD_1206 | Резистор | ROYALOHM | Тайвань | 20 0,25Вт 1% | 1206 | 20 0,25Вт 1% 1206 (ROYALOHM, Тайвань) | 2 | R2, R3
4,7k | R_SMD_1206 | Резистор | ROYALOHM | Тайвань | 4,7k 0,25Вт 1% | 1206 | 4,7k 0,25Вт 1% 1206 (ROYALOHM, Тайвань) | 1 | R4
510 | R_SMD_1206 | Резистор | ROYALOHM | Тайвань | 510 0,25Вт 1% | 1206 | 510 0,25Вт 1% 1206 (ROYALOHM, Тайвань) | 6 | R5, R6, R8, R9, R10, R11
470 | R_SMD_1206 | Резистор | ROYALOHM | Тайвань | 470 0,25Вт 1% | 1206 | 470 0,25Вт 1% 1206 (ROYALOHM, Тайвань) | 1 | R7
USB_B | USB mini B 10033526-N3212LF | Разъём | Connfly electronic | Китай | Mini USB type-B DS1104 |  | Mini USB type-B DS1104 (Connfly electronic, Китай) | 1 | XS1
SWD | PLS-4 | Разъём | Connfly electronic | Китай | PLS-4 |  | PLS-4 (Connfly electronic, Китай) | 1 | XS2
XS3 | ZIF 14P socket | Разъём | Connfly electronic | Китай | ZIF 14P |  | ZIF 14P (Connfly electronic, Китай) | 1 | XS3

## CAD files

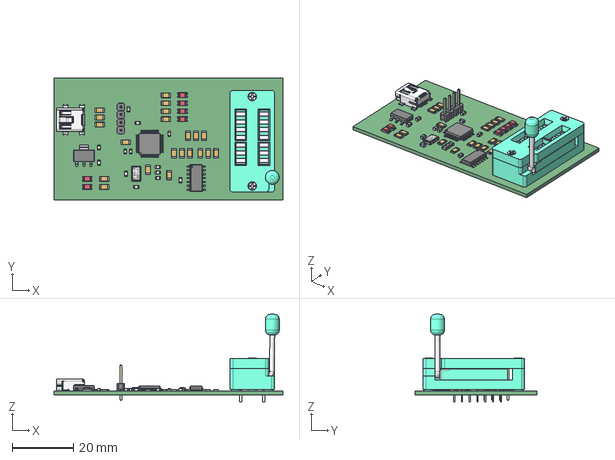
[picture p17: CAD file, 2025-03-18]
hardware/kompas/3d/PCB.step
75.0 x 40.0 x 28.7 mm

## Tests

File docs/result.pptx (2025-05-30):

МИНИСТЕРСТВО НАУКИ И ВЫСШЕГО ОБРАЗОВАНИЯ РОССИЙСКОЙ ФЕДЕРАЦИИ
МОСКОВСКИЙ ГОСУДАРСТВЕННЫЙ ТЕХНИЧЕСКИЙ УНИВЕРСИТЕТ ИМ. Н.Э. БАУМАНА
КАФЕДРА ПРОЕКТИРОВАНИЕ И ТЕХНОЛОГИЯ ПРОИЗВОДСТВА ЭЛЕКТРОННОЙ АППАРАТУРЫ






Отчет о выполнении курсовой работы по предмету: «Электроника и микроэлектроника» на тему: «Тестер компонентов на базе микроконтроллера STM32F103C8T6»






Выполнил: студент группы ИУ4-62Б
Наумов И.К.
Проверил: Руководитель курсовой работы
Чистяков М.Г.



Москва, 2024 г.

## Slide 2

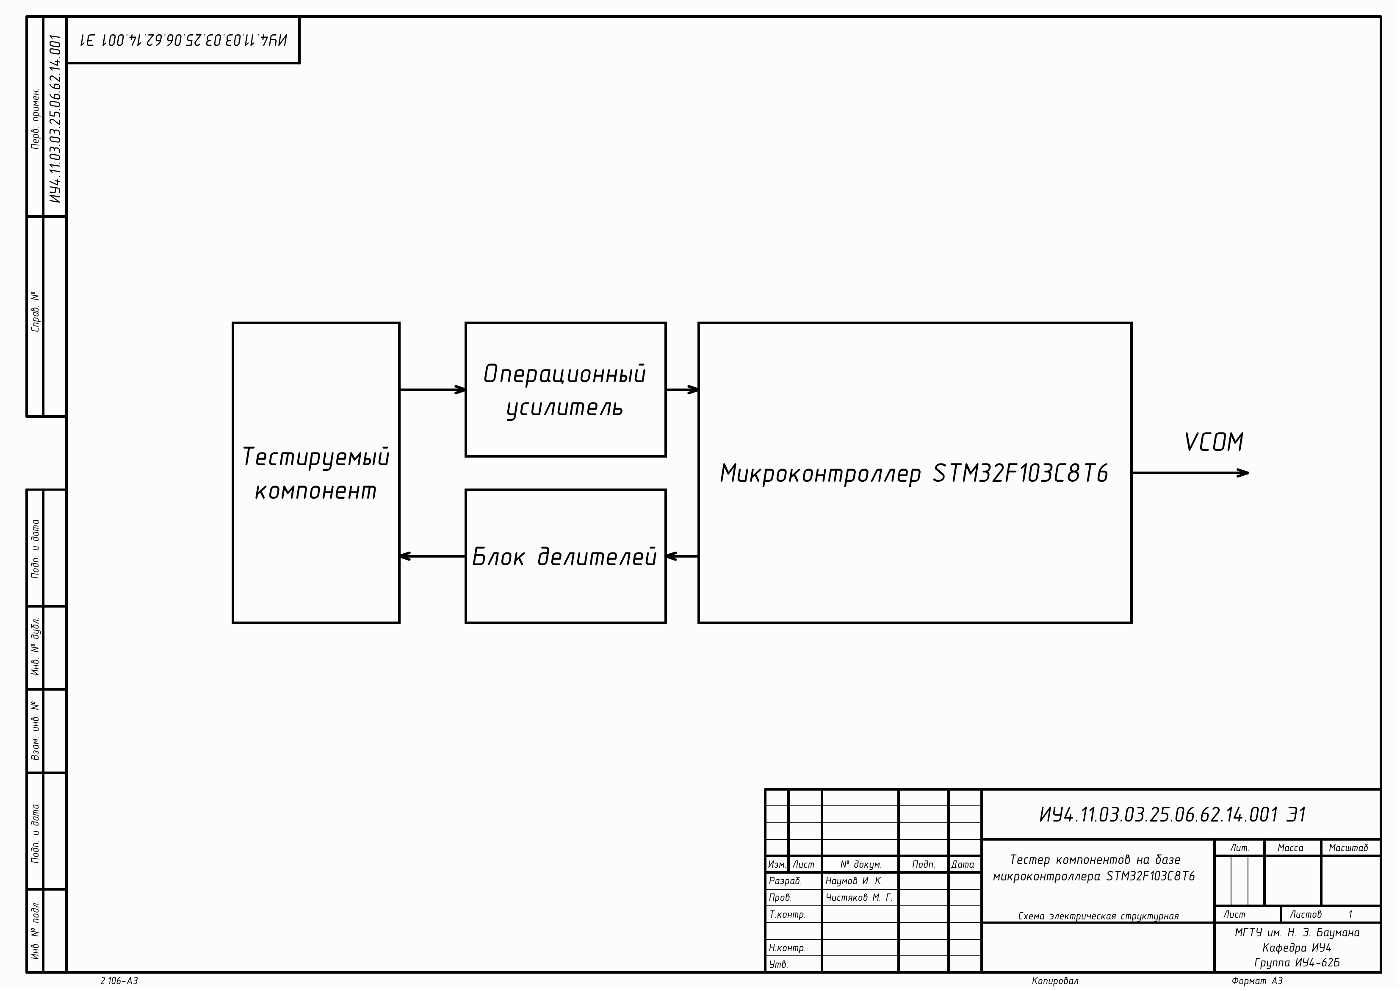
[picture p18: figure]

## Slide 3

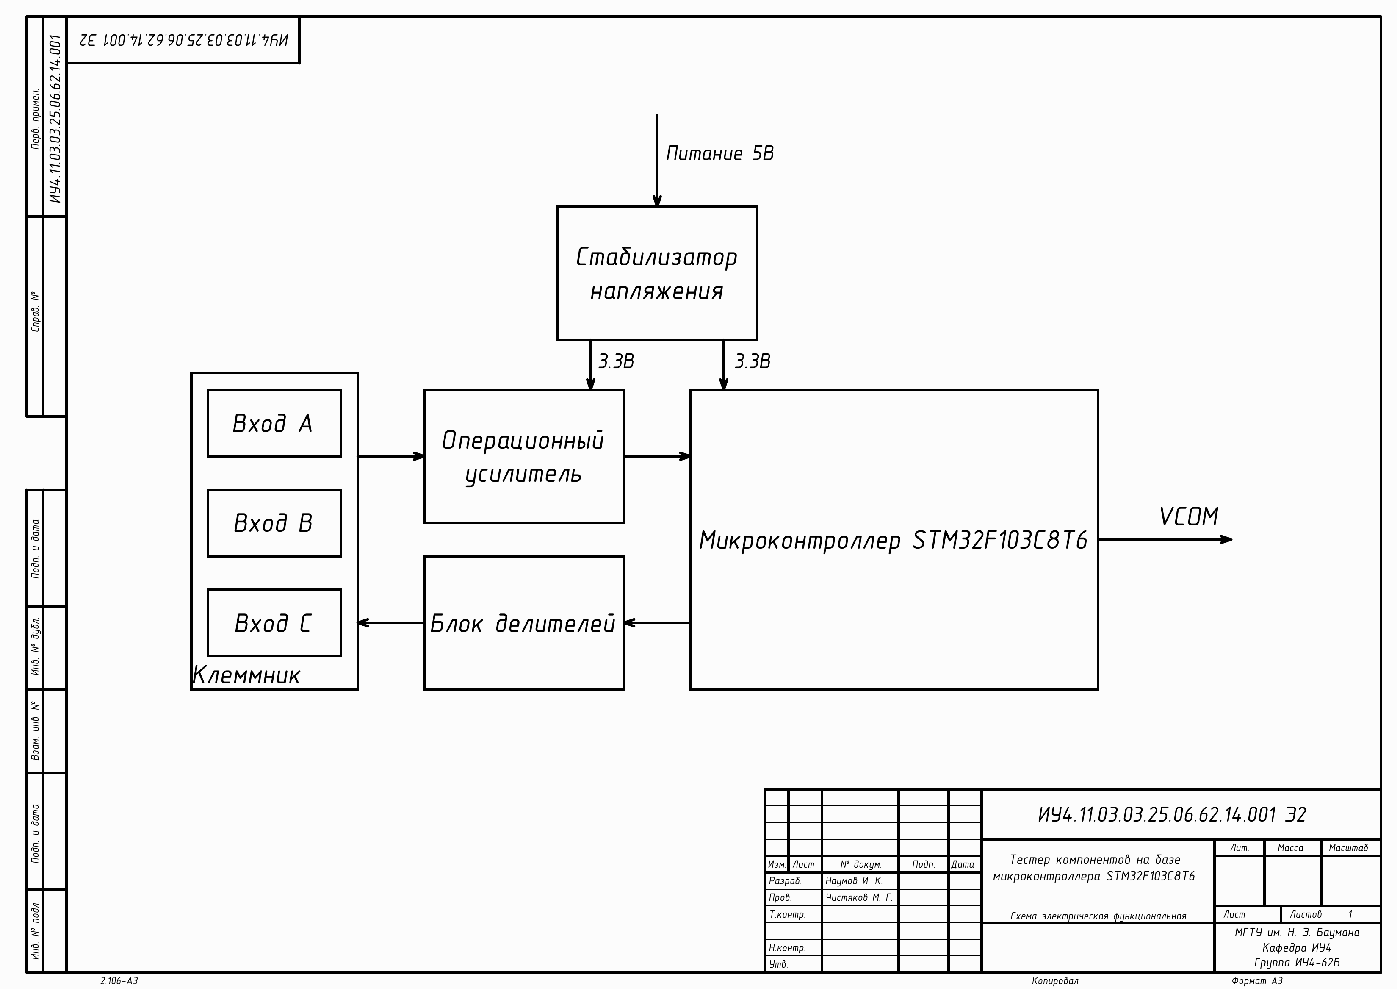
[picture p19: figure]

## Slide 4

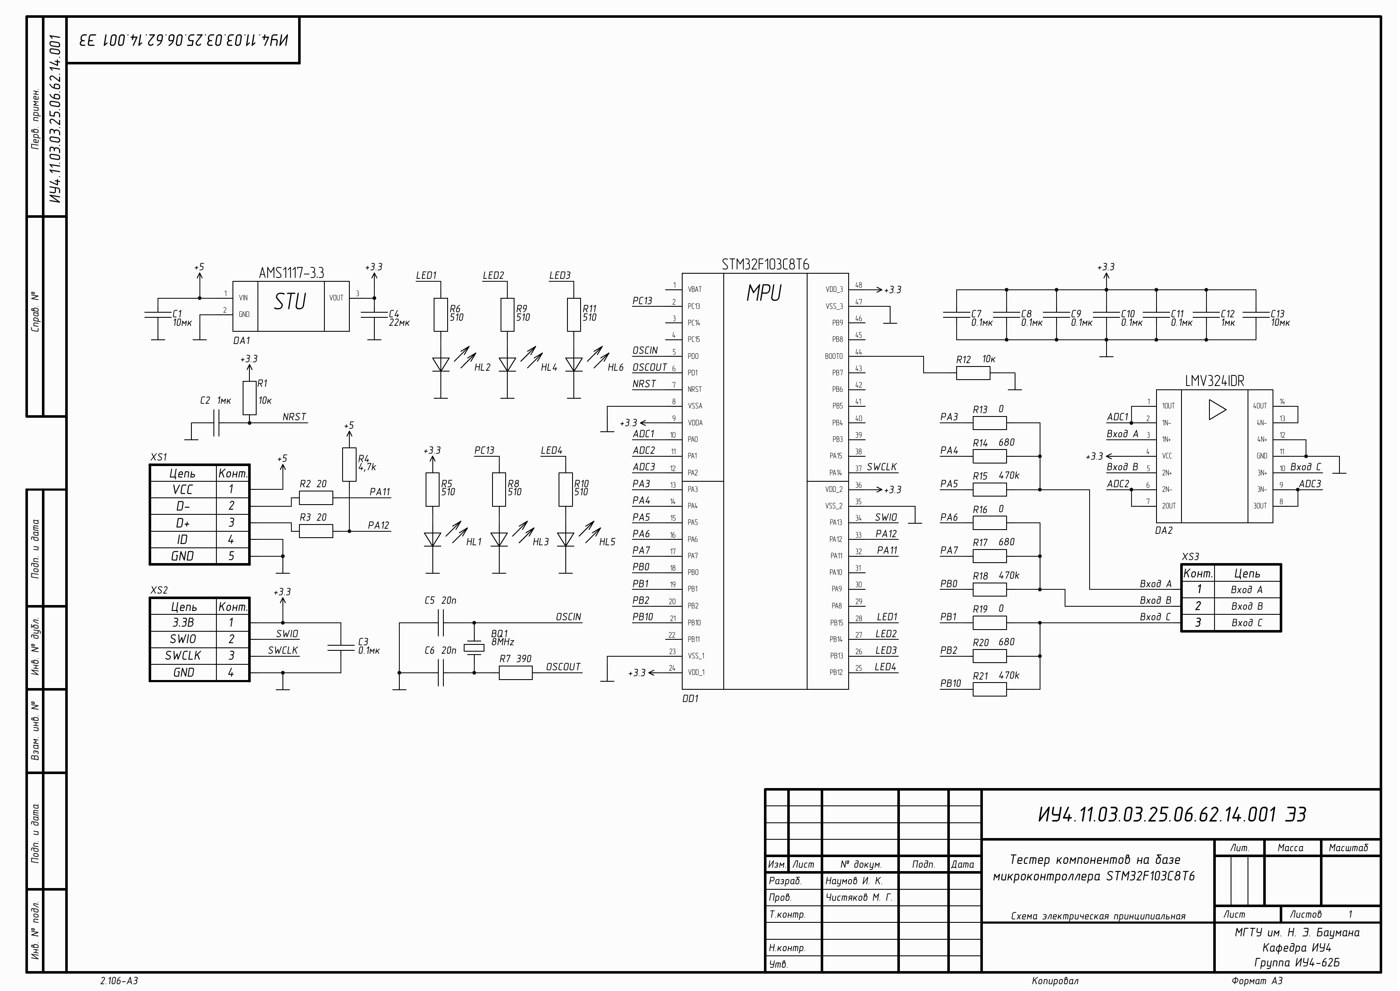
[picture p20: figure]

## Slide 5

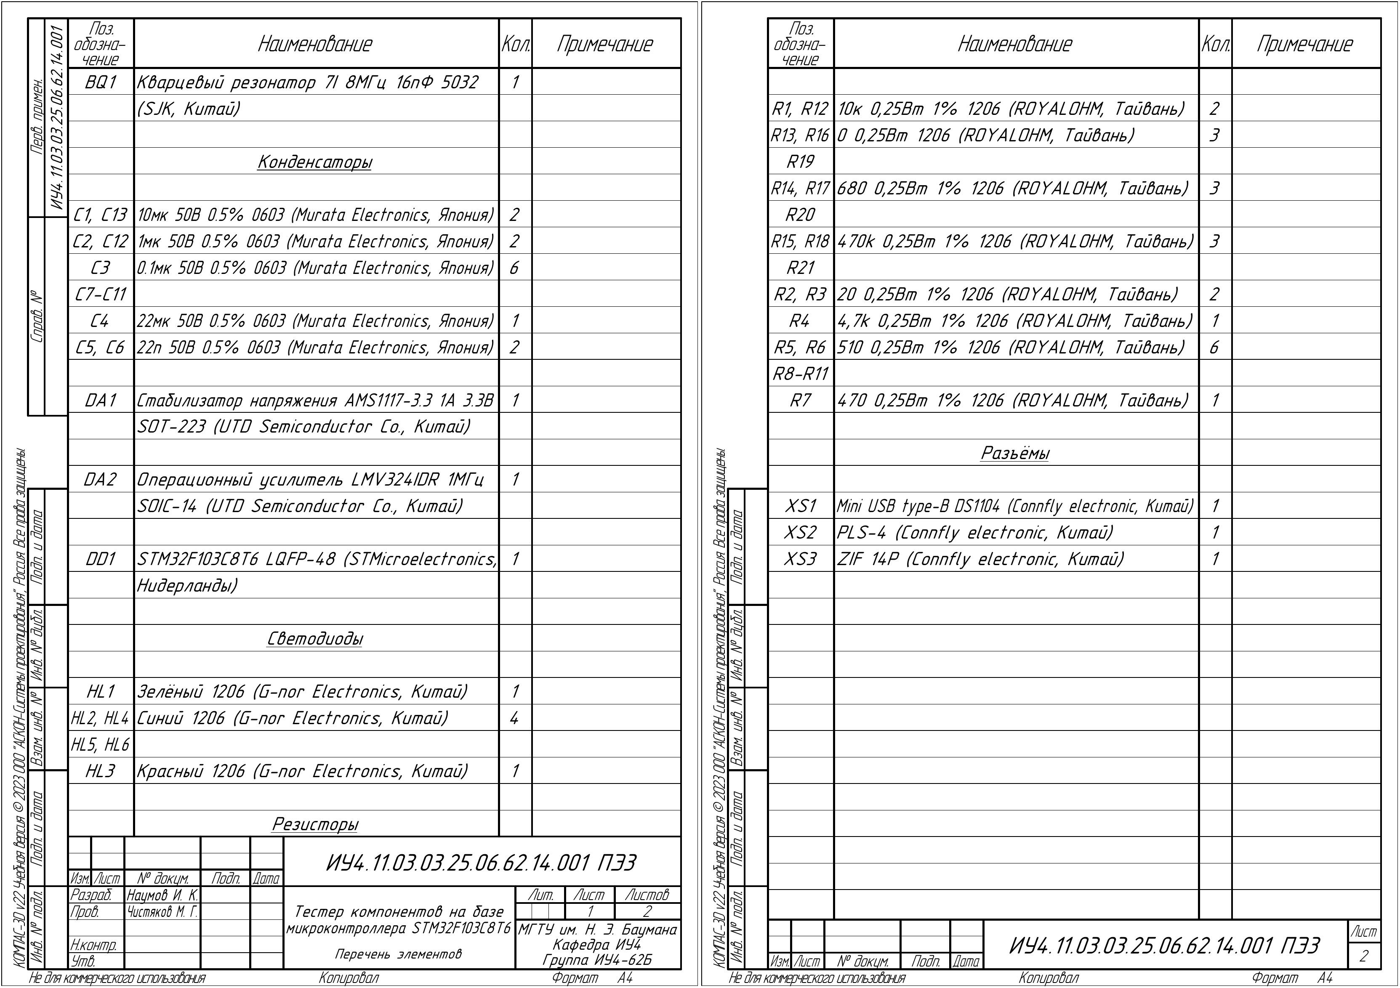
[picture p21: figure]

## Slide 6

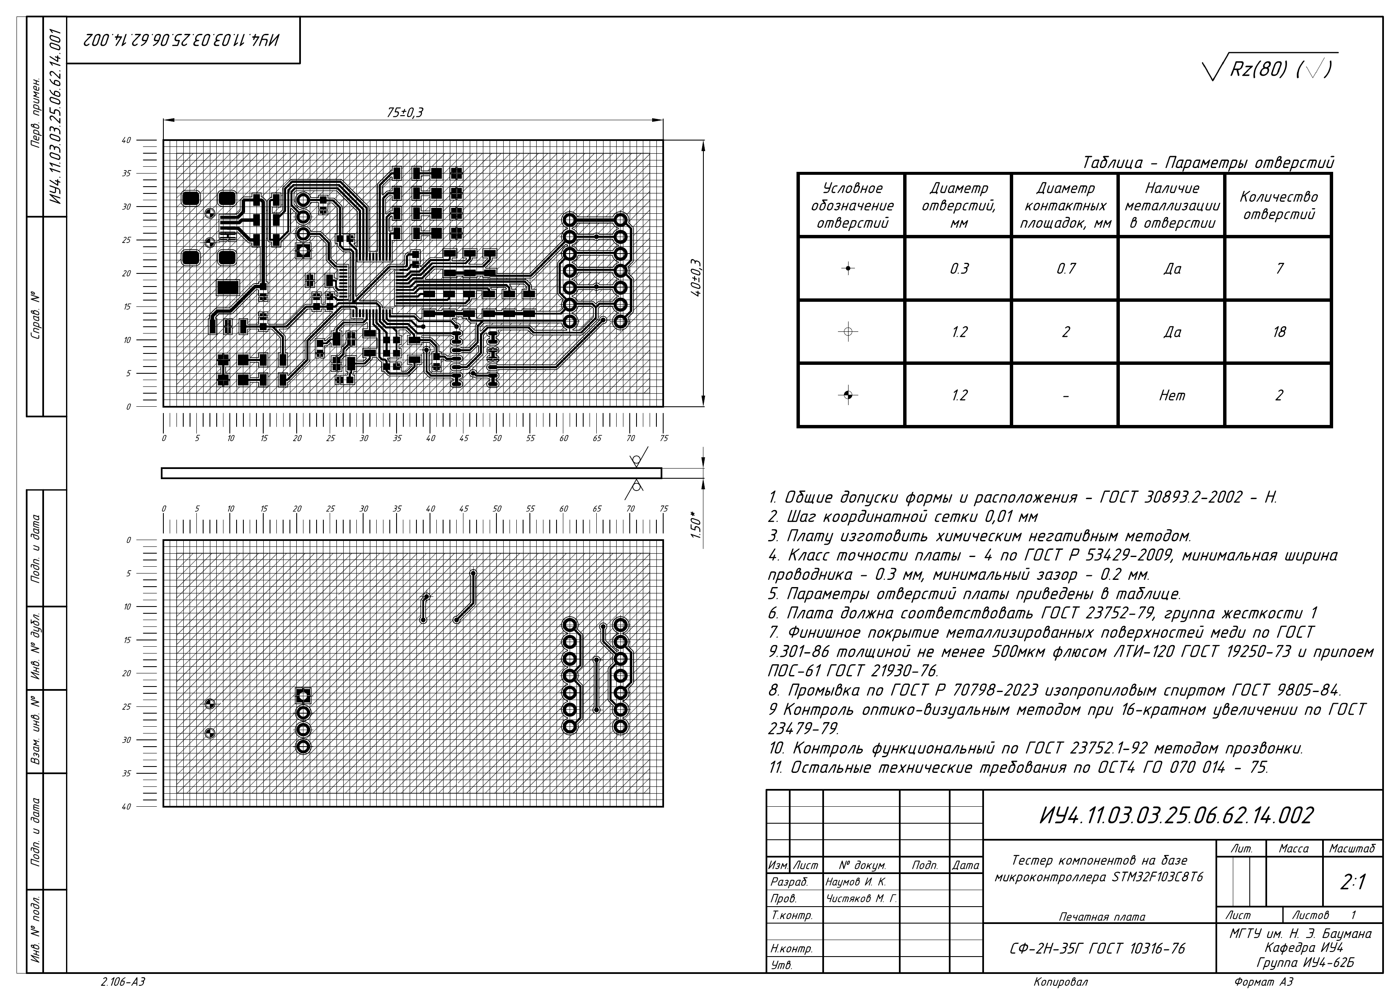
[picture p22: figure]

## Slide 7

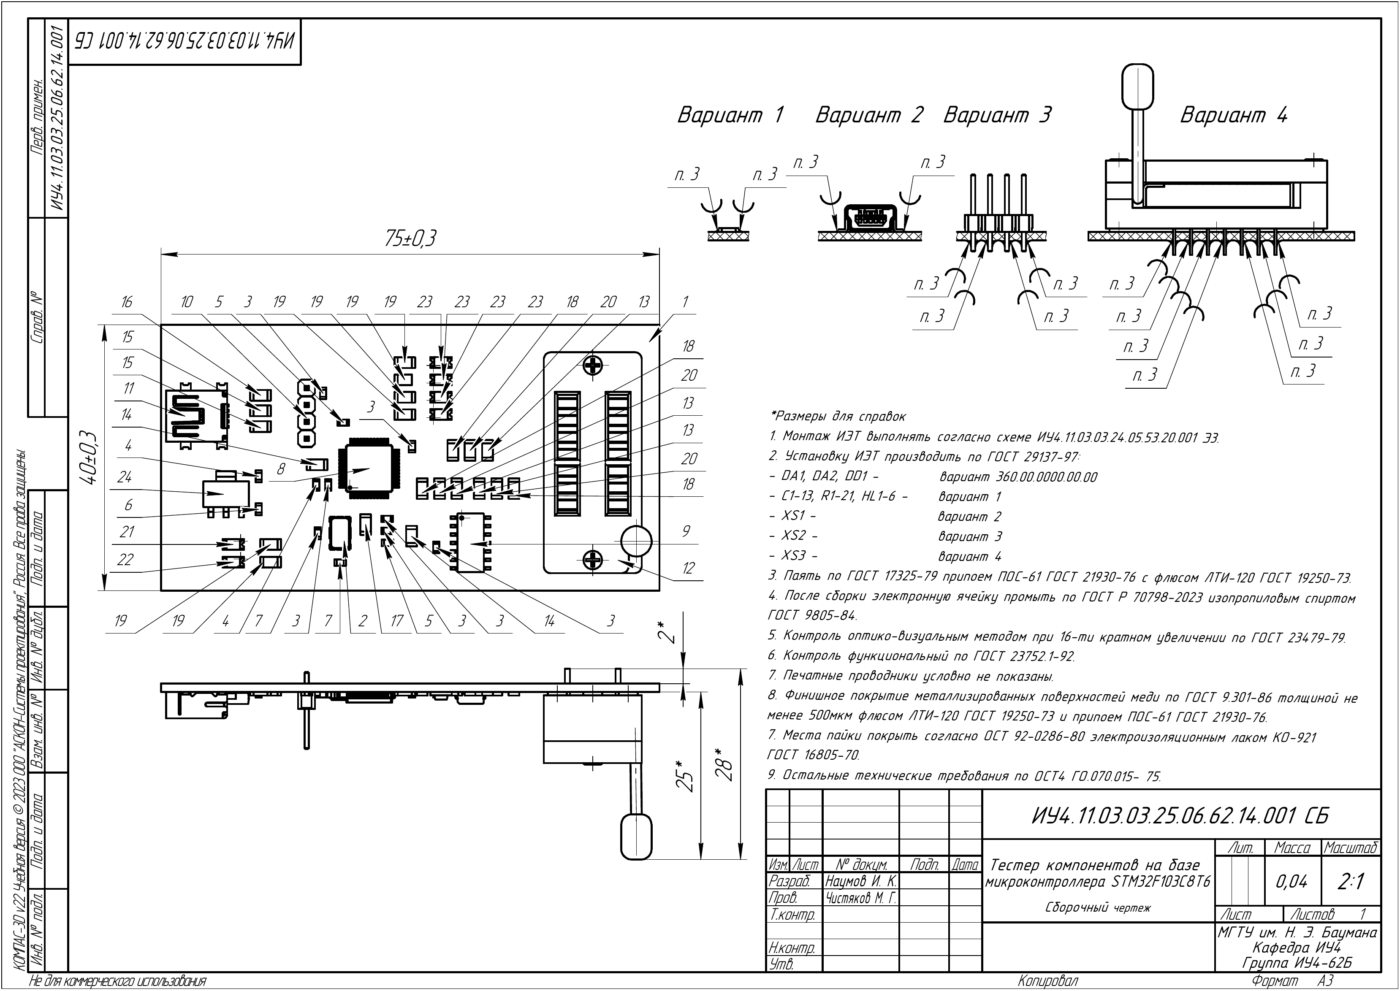
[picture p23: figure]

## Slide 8

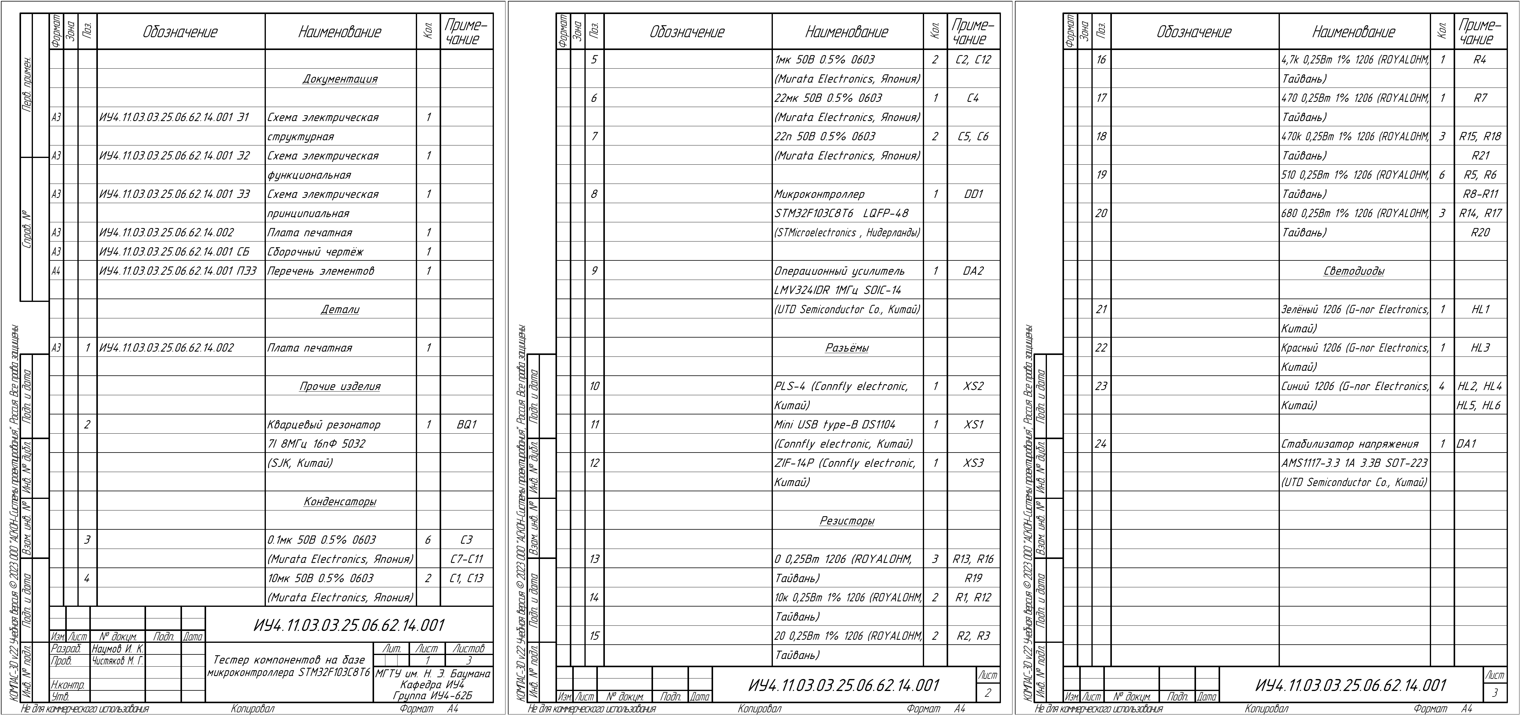
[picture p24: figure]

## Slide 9

- {{modeling.pdf}}

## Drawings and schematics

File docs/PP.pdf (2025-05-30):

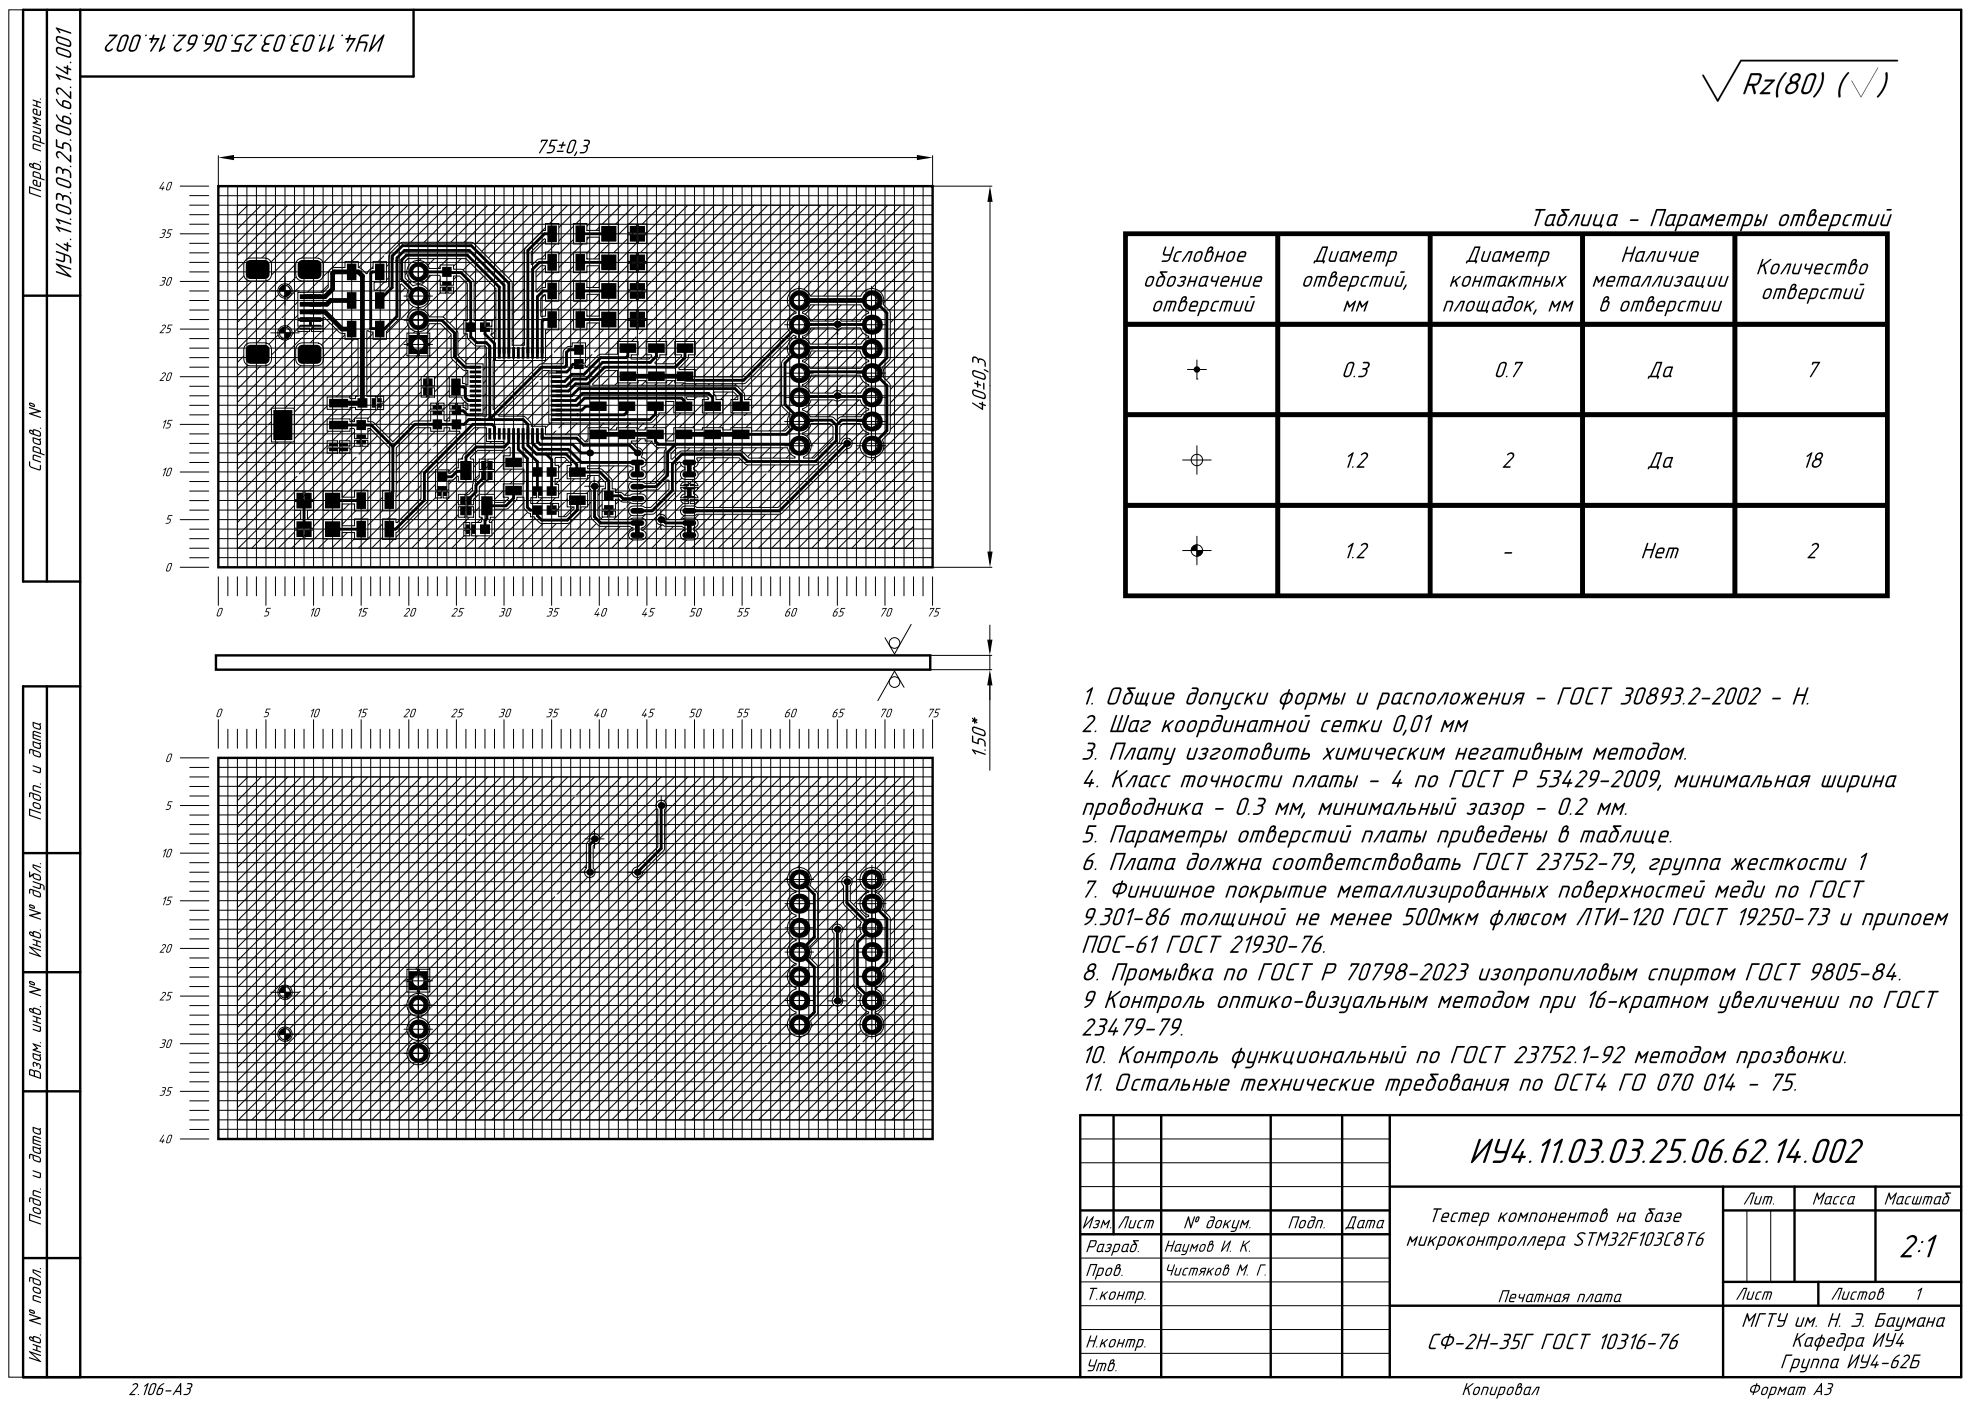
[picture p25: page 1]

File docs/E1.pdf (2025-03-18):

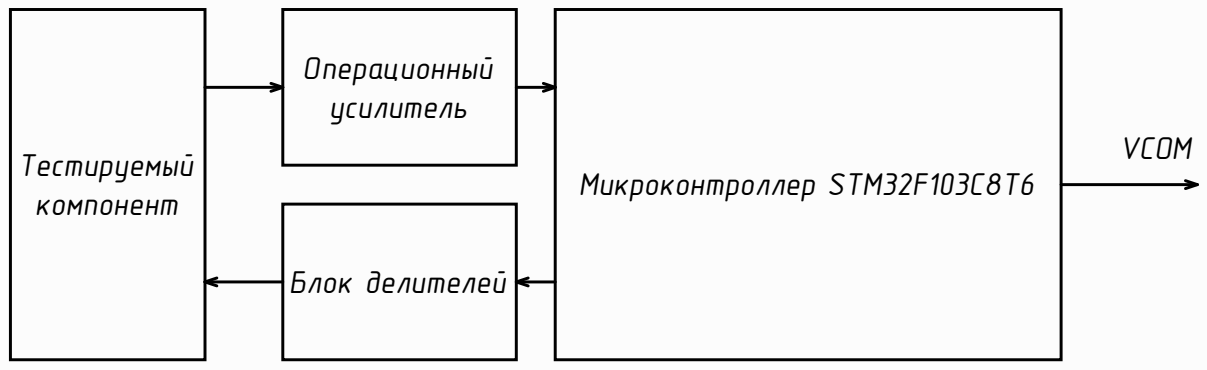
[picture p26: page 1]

Подп. и дата Перв. примен. Справ. №

Инв. № подл. Инв. № дубл. Подп. и дата Взам. инв. №

Тестер компонентов на базе микроконтроллера STM32F103C8T6 Схема электрическая структурная | Лит. | Масса | Масштаб

Изм. | Лист | № докум. | Подп. | Дата
Разраб. | | Наумов И. К.
Пров. | | Чистяков М. Г.
Т.контр. | | | | | Лист | Листов 1

МГТУ им. Н. Э. Баумана Кафедра ИУ4 Группа ИУ4-62Б

Н.контр.
Утв.

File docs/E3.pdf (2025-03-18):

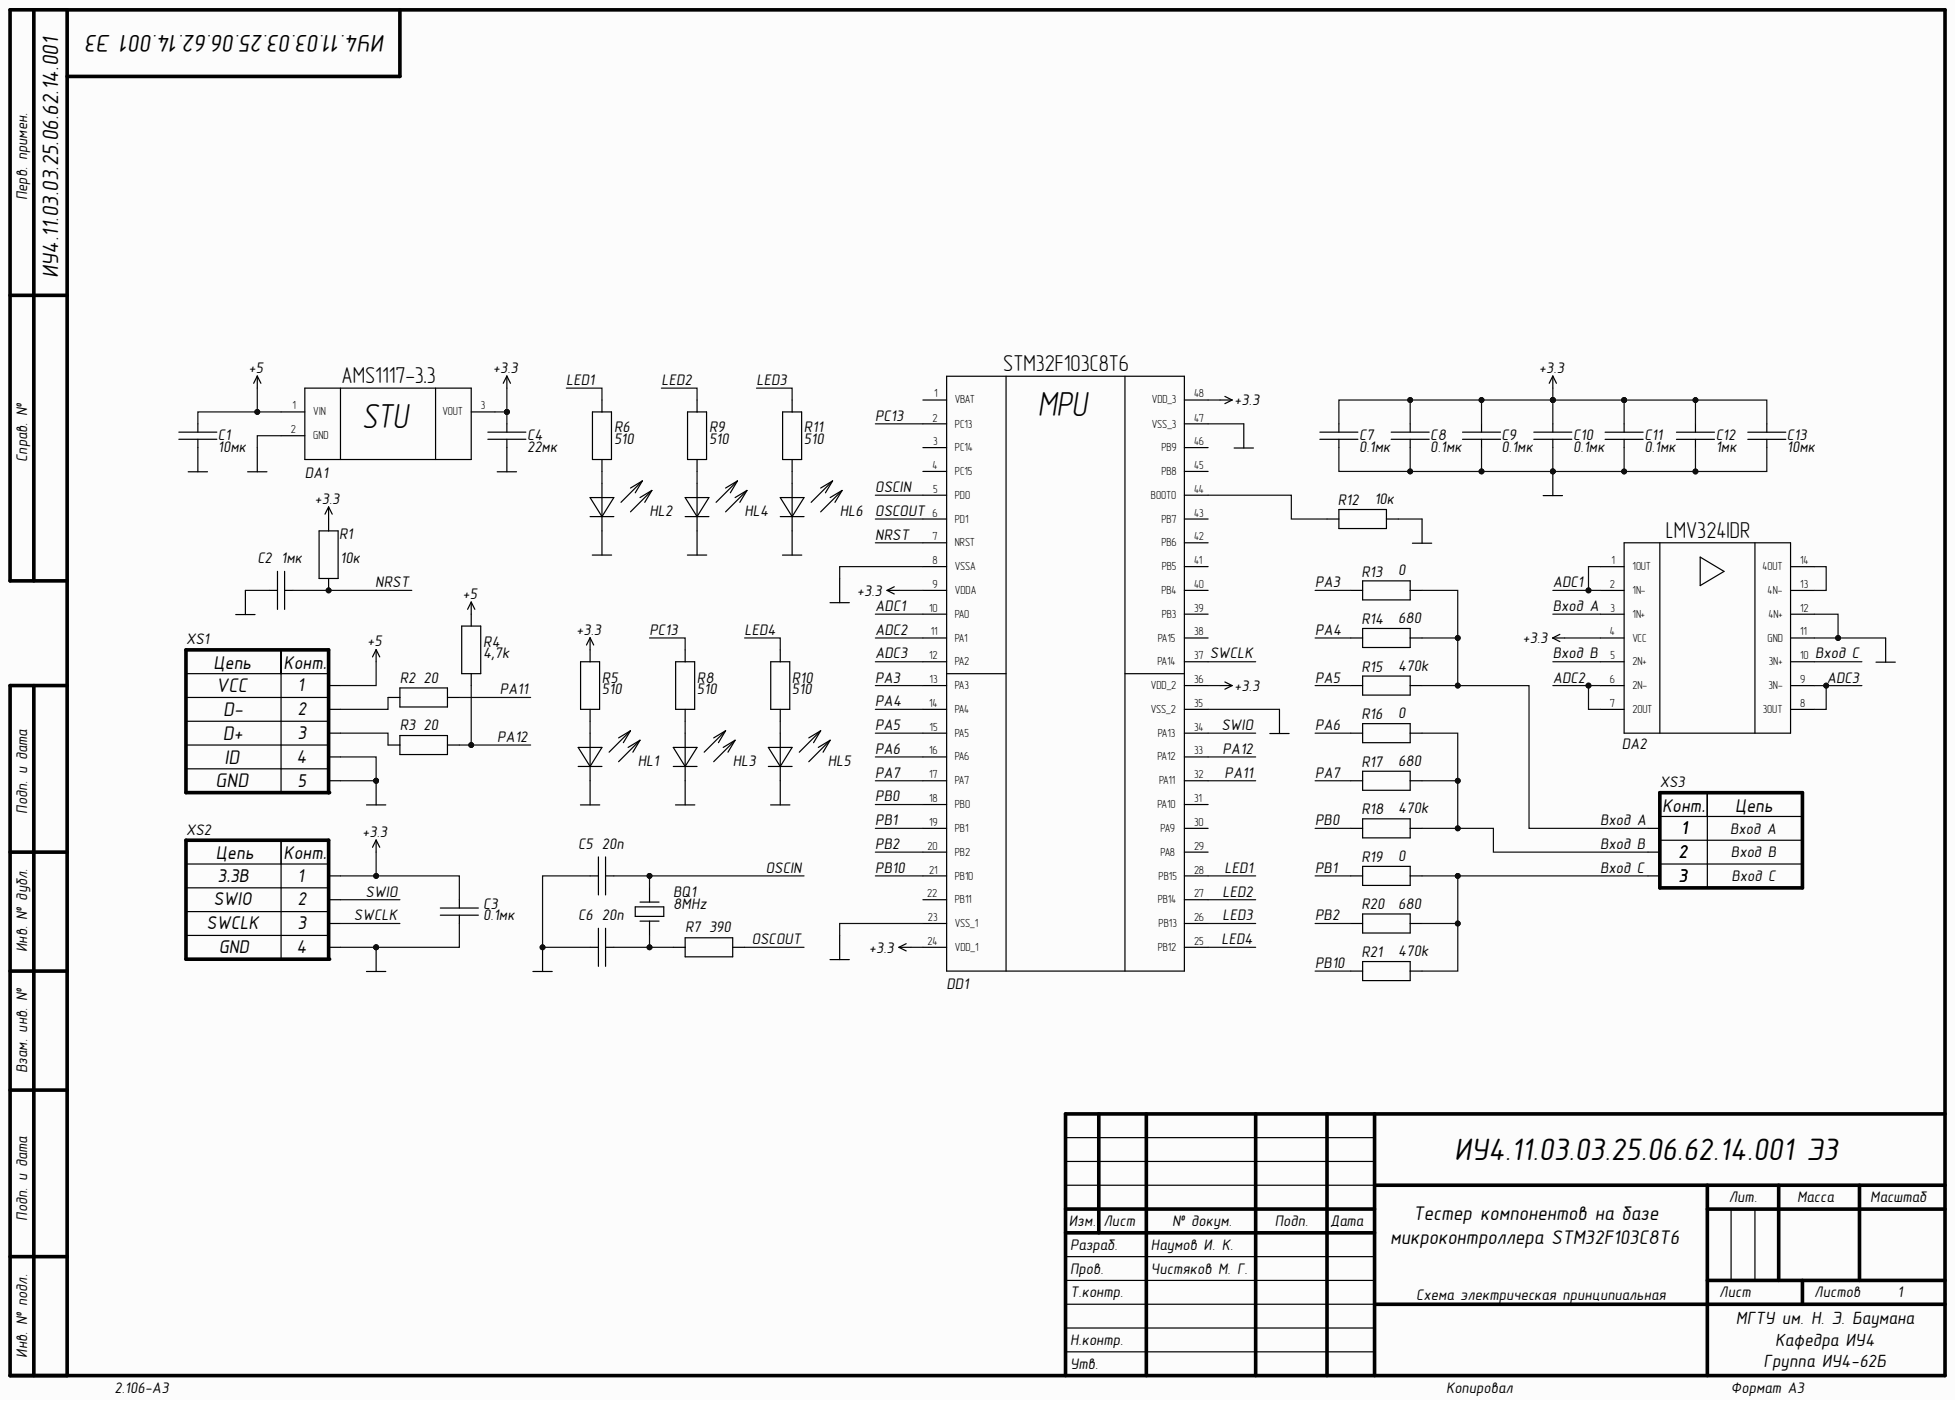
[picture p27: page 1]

Инв. № подл. Инв. № дубл. Подп. и дата Взам. инв. № Подп. и дата Перв. примен. Справ. №

Тестер компонентов на базе микроконтроллера STM32F103C8T6 Схема электрическая принципиальная | Лит . | Мас с а | Масштаб

Изм . | Лис т | № докум . | Подп . | Дата
Разраб . | | Наумов И. К .
Пров . | | Чистяков М. Г .
Т .контр . | | | | | Лис т | Листов 1

МГТУ им. Н. Э. Баумана Кафедра ИУ 4 Группа ИУ4-62 Б

Н .контр .
Утв .

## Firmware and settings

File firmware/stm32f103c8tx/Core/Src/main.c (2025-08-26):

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
/* Includes ------------------------------------------------------------------*/
#include "main.h"

#include "usb_device.h"

/* USER CODE BEGIN Includes */

#include "leds.h"
#include "stm32f1xx_ll_gpio.h"
#include "stm32f1xx_ll_utils.h"
#include "tester.h"
#include "usbd_cdc_if.h"
#include "vcom_console.h"

/* USER CODE END Includes */


/* USER CODE BEGIN PV */
leds_t leds_status;
console_t console_status;
tester_t tester_status;
uint32_t tick_counter;

/* USER CODE END PV */

void SystemClock_Config(void);
static void MX_GPIO_Init(void);
static void MX_ADC1_Init(void);
static void MX_TIM3_Init(void);
/* USER CODE BEGIN 0 */
volatile bool run_console_flag = 0;

/* USER CODE END 0 */

/**
 * @brief  The application entry point.
 * @retval int
 */
int main(void) {
    /* MCU Configuration--------------------------------------------------------*/

    /* Reset of all peripherals, Initializes the Flash interface and the Systick. */
    HAL_Init();

    /* Configure the system clock */
    SystemClock_Config();

    /* Initialize all configured peripherals */
    MX_GPIO_Init();
    MX_USB_DEVICE_Init();
    MX_ADC1_Init();
    MX_TIM3_Init();
    /* USER CODE BEGIN 2 */

    leds_init(&leds_status);
    vcom_console_init(&console_status);

    tester_impl_init(&tester_status);

    LL_TIM_EnableIT_UPDATE(TIM3);
    LL_TIM_EnableCounter(TIM3);
    /* USER CODE END 2 */

    /* Infinite loop */
    /* USER CODE BEGIN WHILE */
    // bool run_tester = true;
    uint32_t last_toggle = 0;
    while (1) {
        if (run_console_flag) {
            vcom_console_process(&console_status);
            run_console_flag = 0;
        }
        /* USER CODE END WHILE */

        /* USER CODE BEGIN 3 */
        if (get_tick_count() - last_toggle >= 500) {
            leds_toggle(&leds_status, LED_RED);
            last_toggle = get_tick_count();
        }

#if 0
        if (tick_counter > 1000 && run_tester) {
            component_t component = tester_test_resistor(&tester_status);
            component_to_str(&component, console_tx_buffer);
            console_status.write(console_tx_buffer);
            run_tester = false;
        }
#endif
    }
    /* USER CODE END 3 */
}

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


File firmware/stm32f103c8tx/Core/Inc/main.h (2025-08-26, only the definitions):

#define LED_Pin LL_GPIO_PIN_13
#define LED_GPIO_Port GPIOC
#define PIN_A_ADC_Pin LL_GPIO_PIN_0
#define PIN_A_ADC_GPIO_Port GPIOA
#define PIN_B_ADC_Pin LL_GPIO_PIN_1
#define PIN_B_ADC_GPIO_Port GPIOA
#define PIN_C_ADC_Pin LL_GPIO_PIN_2
#define PIN_C_ADC_GPIO_Port GPIOA
#define PIN_A_0Ohm_Pin LL_GPIO_PIN_3
#define PIN_A_0Ohm_GPIO_Port GPIOA
#define PIN_A_680Ohms_Pin LL_GPIO_PIN_4
#define PIN_A_680Ohms_GPIO_Port GPIOA
#define PIN_A_470kOhms_Pin LL_GPIO_PIN_5
#define PIN_A_470kOhms_GPIO_Port GPIOA
#define PIN_B_0Ohm_Pin LL_GPIO_PIN_6
#define PIN_B_0Ohm_GPIO_Port GPIOA
#define PIN_B_680Ohms_Pin LL_GPIO_PIN_7
#define PIN_B_680Ohms_GPIO_Port GPIOA
#define PIN_B_470kOhms_Pin LL_GPIO_PIN_0
#define PIN_B_470kOhms_GPIO_Port GPIOB
#define PIN_C_0Ohm_Pin LL_GPIO_PIN_1
#define PIN_C_0Ohm_GPIO_Port GPIOB
#define PIN_C_680Ohms_Pin LL_GPIO_PIN_2
#define PIN_C_680Ohms_GPIO_Port GPIOB
#define PIN_C_470kOhms_Pin LL_GPIO_PIN_10
#define PIN_C_470kOhms_GPIO_Port GPIOB
#define LED_Transistor_Pin LL_GPIO_PIN_12
#define LED_Transistor_GPIO_Port GPIOB
#define LED_Diode_Pin LL_GPIO_PIN_13
#define LED_Diode_GPIO_Port GPIOB
#define LED_Capacitor_Pin LL_GPIO_PIN_14
#define LED_Capacitor_GPIO_Port GPIOB
#define LED_Resistor_Pin LL_GPIO_PIN_15
#define LED_Resistor_GPIO_Port GPIOB

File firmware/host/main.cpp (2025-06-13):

#define CATCH_CONFIG_RUNNER

#include <iostream>

#include "console.h"
#include "leds.h"

#ifdef DEBUG_MODE
#include <unistd.h>

#include "fifo_console.h"
#else
#endif  // DEBUG_MODE
#include "catch.hpp"

extern "C" {
#include "log.h"
}

leds_t leds_status;

#define LOG_DEFAULT_LEVEL LOG_DEBUG

int main(int argc, char** argv) {
    log_set_level(LOG_DEFAULT_LEVEL);
    leds_init(&leds_status);

#ifdef DEBUG_MODE
    // Arbitrary code for debug modules
    (void)argc;
    (void)argv;

    log_trace("trace");
    log_debug("debug");
    log_info("info");
    log_warn("warn");
    log_error("error");
    log_fatal("fatal");

    console_t console;
    fifo_console_init(&console, true);

    while (1) {
        fifo_console_process(&console);
        usleep(100);
    }

    fifo_console_deinit(&console);

    return 0;
#else
    // Tests runner
    int result = Catch::Session().run(argc, argv);
    return result;
#endif  // DEBUG_MODE
}

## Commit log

2025-01-05 Fix stm32f103 readme
2025-01-05 Add leds module
2025-02-10 Add host led impl, test and command
2025-02-18 Add Altium project: E1, E3, A3-templates
    [E1.SchDoc, E2.SchDoc, E3.SchDoc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]
2025-02-19 Fix E1
    [E1.SchDoc]
2025-02-21 Edit E1, E2, E3
    [E1.SchDoc, E2.SchDoc, E3.SchDoc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]
2025-02-24 Fix mistakes on E1, E2, E3
    [E1.SchDoc, E2.SchDoc]
2025-02-24 Edit E3, PCB
    [E3.SchDoc, PCB.PcbDoc, component_tester.PrjPcb]
2025-02-25 Fix E1, E2, E3
    [E1.SchDoc, E2.SchDoc, E3.SchDoc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]
2025-02-26 Fix E1, E2 name
    [E1.SchDoc, E2.SchDoc]
2025-02-26 Fix E3
    [E3.SchDoc, PCB.PcbDoc, component_tester.PrjPcb]
2025-02-26 Fix PCB
    [E3.SchDoc, PCB.PcbDoc, component_tester.PrjPcb]
2025-03-02 Add stend
    [component_tester.PrjPcb]
2025-03-06 Fix E3, PCB
    [E3.SchDoc, PCB.PcbDoc, component_tester.PrjPcb]
2025-03-12 Add BOM.xlsx
    [BOM.xlsx]
2025-03-16 Fix PCB, E3, create SB, PP, PE3, speka
    [BOM.xlsx, E3.SchDoc, PCB.PcbDoc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]
2025-03-16 Fix PCB 3d model and SB
    [E3.SchDoc, PCB.PcbDoc, PCB.step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]
2025-03-17 Fix PLS on 3d model, SB
    [PCB.PcbDoc, PCB.step]
2025-03-18 Finish PP
    [PCB.PcbDoc]
2025-03-19 Fix PP
    [PCB.PcbDoc]
2025-03-21 Add capacitor and resistor simulation
2025-03-21 Fix PP, SB
    [PCB.PcbDoc]
2025-04-02 Fix PCB to fabric
    [PCB.PcbDoc]
2025-05-30 Fix led module
2025-06-08 init tester
    [stlink.cfg]

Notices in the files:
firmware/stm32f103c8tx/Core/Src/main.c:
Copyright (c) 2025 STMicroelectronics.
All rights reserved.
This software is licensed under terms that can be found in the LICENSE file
